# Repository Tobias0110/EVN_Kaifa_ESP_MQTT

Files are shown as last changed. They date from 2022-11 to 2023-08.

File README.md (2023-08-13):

# EVN Kaifa to MQTT
Allows you to read data from different kinds of smart power meters used by the
EVN power company in Austria. Data is read from the MBus interface (called P1),
packages are decrypted and then the values are sent to an MQTT endpoint. The
device hosts a webpage, where you can change your settings.

## 🤔 How does it work?
The ESP8266 receives the MBus data from the smart meter via a UART interface on the
front facing side of the device. A specially developed interface PCB powers the
micro-controller board from the MBus idle voltage (no extra power supply needed).
In addition, it contains a level shifter to convert from MBus voltage levels to
3V3 UART compatible with the ESP8266. This is useful because many people don't
have a power socket near their power meter.

**Please consider buying the PCB from me to support our work. You can contact me via oe3tec(at)egimoto.com**

The ESP8266 micro-controller syncs to the smartmeter's bursts of data so no packets
are lost. After receiving a package it is decrypted and the DSLM/COSEM data structure
is parsed to extract the measurement fields. These fields are then sent to an MQTT
broker in a preselected format. All relevant parameters can be configured via the
serial console at startup and are saved to the EEPROM.

Alternatively, you can update your configuration on the webpage that the ESP hosts
on the wifi network. The page is only accessible with a passcode that is set during
first setup. For more details on the webpage see below.

<p align="center">
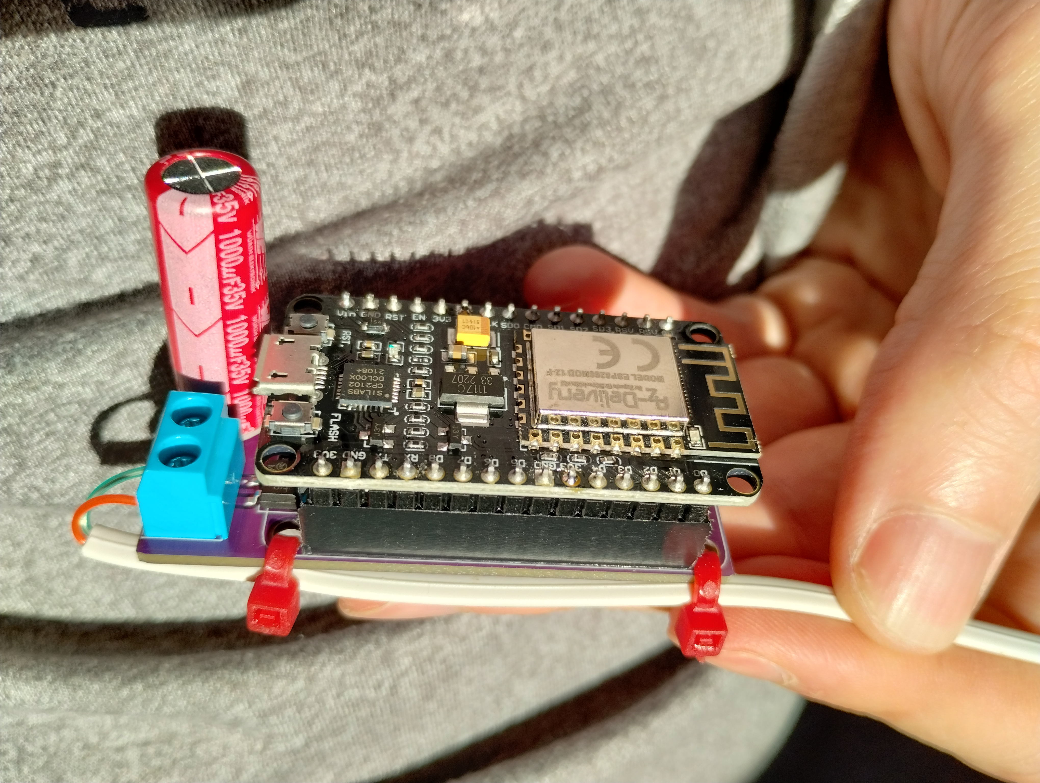
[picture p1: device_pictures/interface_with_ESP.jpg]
Complete assembly of the custom PCB and the ESP8266 on top
  
</p>

## 🔧 Installation
> **Note**
> Make sure the ESP is not connected to the interface board during programming or
> configuration.

The following steps are applicable if you are using the Arduino IDE to build the
project yourself.

1. Install [NodeJS](https://nodejs.org) on your machine, and navigate to the `www` directory.
   There, install the required npm packages by running `npm i` in your console.
2. Run the webpage build script. This should create a file named `settings-page.html.inl.h`
   next to the Arduino sketch file.
3. Install the ESP-Module as a compilation target.
    1. Add board config repository: File → Preferences →
       Paste URL into "Additional boards manager URLs": [http://arduino.esp8266.com/stable/package_esp8266com_index.json](http://arduino.esp8266.com/stable/package_esp8266com_index.json)
    2. Install the toolchain: Tools → Boards Manager → Install: esp8266
    3. Select the specific ESP module: Tools → Board → ESP2866 Boards → NodeMCU 1.0 (ESP-12E Modul)
4. Open the Library Manager pane and install the following dependecies.
    * [Crypto](https://github.com/rweather/arduino-projects) by Rhys Weatherley
    * [PubSubClient](https://github.com/knolleary/pubsubclient) by Nicholas O'Leary
    * [CRC](https://github.com/RobTillaart/CRC) by Rob Tillaart
5. Manully install the following dependencies by downloading their source code and
   dropping it into your `Arduino/Libraries` directory.
    * [ESPTrueRandom8266](https://github.com/marvinroger/ESP8266TrueRandom) by Marvin Roger
6. Click verify to check if the project builds without errors.
7. Connect the ESP module and click upload like for any other Arduino-like micro controller.
8. Connect to the ESP2866 through the serial monitor and start configuration.

## ⚙ Configuration via serial
> **Note**
> Make sure the ESP is not connected to the interface board during programming or
> configuration.

First configuration of the device is done via the serial terminal and is guided
by an interactive setup wizard. On first startup the checksum check will fail and
you will be required to enter settings. Later, you can enter the setup wizard
again during the first 10 seconds after starting by pressing 's'. You can also
clear your configuration by pressing 'c'.

1. Connect the ESP board via USB to your computer and open a serial terminal.
   Serial settings: 115200 Baud, NO Parity
2. Press reset on the ESP board.
3. On first startup the setup wizard starts immediately. Else press 's' on your
   keyboard when you are prompted to do so to edit the current settings.
4. The configuration wizard shows each settings field. Enter the data for each field
   and press return. Some fields come with default values, which are accepted by
   pressing return without any other input.
5. After start up the system switches the serial interface to MBus mode (2400 baud,
  even parity) and waits for data packets.

To boot the ESP with your settings, reset the micro-controller. All the settings fields that
can be configured are listed in the table below.

| Field name | Default value | Description |
| :--- | :--- | :--- |
WiFi SSID || SSID of the WiFi station to connect to |
WiFI password || Password of the WiFi station to connect to |
MQTT broker network address || Domain/IP of the MQTT broker server |
MQTT broker network port | 1883 | Network port of the MQTT broker server |
MQTT broker certificate fingerprint | [insecure] | SHA1 fingerprint of the SSL certificate of the MQTT broker server as hex string. If set to `[insecure]` TLS is disabled and all data is sent as plaint text |
MQTT broker user name | power-meter | User name to authenticate at the MQTT broker server |
MQTT broker password || Password to authenticate at the MQTT broker server |
MQTT broker client id || Client id to register as at the MQTT broker server |
MQTT broker path || Base path prepended to MQTT topics |
MQTT message mode | 2 | Selects the format for sending the data fields to the MQTT broker server (0 - raw, 1 - topics, 2 - json) |
Webpage key | _automatically generated random value_ | Passkey to access the webpage |
DSLM/COSEM decryption key (meter key) || Decryption key to decipher the MBus data packets provided by the power company |

> **Note**
> When reconnecting the micro-controller PCB to the interface PCB make sure that the pins align correctly.
> Also check that the USB connector points in the direction of the M-Bus connector. Wrong positioning can result in a short and damage the microcontroler.

## 🌍 Configuration via webpage
After initial setup with the serial interface and having the ESP connected to
the wifi, you can connect to the configuration webpage. To access it you need
the passkey you set before.

Due to memory limitation of the ESP8266 only a single TLS tunnel can be used at
once. As one is needed for the secure mqtt connection, there are no resources left
for the webserver. Therefore an alternative security scheme is used and the
page is hosted as plain HTTP. This means, that all your settings are always
transmitted encrypted and unreadable to others.

For security reasons, especially sensitive fields are not automatically populated
in their respective form fields. When you edited any settings and saved your changes
they will only take effect after restarting the device.

## 📬 MQTT output formats
> **Note**
> 🔐 When using secure MQTT, make sure to put `tls_version tlsv1.2` in your MQTT
> servers config file, so it only accepts encrypted connections!

The system can be configured to output the data received from the smartmeter in one
of the following formats.

### 🥩 Raw
The decryptd raw data without DSLM/COSEM parsing is sent to the broker at
`<basepath/raw>`. The data is sent as binary.

### 🐧 JSON
If the data is serialized as JSON, it is sent to the broker at `<basepath>/json`.
The json object has the following format.

| Field name  | Type | Full name  | Description |
| :--- | :--- | :--- | :--- |
| meternumber | string[12] || The unique identification number of the smartmeter |
| timestamp | ISO timestamp || Time when the measurement was taken |
| w_p | number | positive total energy | Total energy consumed |
| w_n | number | negative total energy | Total energy sent back to the grid |
| p_p | number | positive momentary power | Power currently consumed |
| p_n | number | negative momentary power | Power currently sent back to the grid |
| u1 | number | voltage on phase 1 | Momentary voltage measured on phase 1 |
| u2 | number | voltage on phase 2 | Momentary voltage measured on phase 2 |
| u3 | number | voltage on phase 3 | Momentary voltage measured on phase 3 |
| i1 | number | current on phase 1 | Momentary current measured on phase 1 |
| i2 | number | current on phase 2 | Momentary current measured on phase 2 |
| i3 | number | current on phase 3 | Momentary current measured on phase 3 |
| phi | number | power factor | Momentary power factor |
| ip | string || IP address received via DHCP |
| rssi | string | Received Signal Strength Indicator | Strength of the wifi signal in `dBm` |

The following JSON is an example package sent by the micro-controller.
```json
{
  "meternumber": "181220000009",
  "timestamp": "2021-09-27T09:47:15+02:00",
  "w_p": 12937,
  "w_n": 0,
  "p_p": 0,
  "p_n": 0,
  "u1": 233.7,
  "u2": 0,
  "u3": 0,
  "i1": 0,
  "i2": 0,
  "i3":0 ,
  "phi":1.000,
  "ip": "192.168.143.51",
  "rssi": "-52dBm"
}
```

### 🔬 Individual topics
If the data fields are sent to individual mqtt topics the following paths are used.
For a description of the fields checkout the section above.

| Field name | Full name  |
| :--- | :--- |
| `<basepath>/meternumber` ||
| `<basepath>/timestamp` ||
| `<basepath>/w_p` | positive total energy |
| `<basepath>/w_n` | negative total energy |
| `<basepath>/p_p` | positive momentary power |
| `<basepath>/p_n` | negative momentary power |
| `<basepath>/u1` | voltage on phase 1 |
| `<basepath>/u2` | voltage on phase 2 |
| `<basepath>/u3` | voltage on phase 3 |
| `<basepath>/i1` | current on phase 1 |
| `<basepath>/i2` | current on phase 2 |
| `<basepath>/i3` | current on phase 3 |
| `<basepath>/phi` | power factor |

## ☔ Standard compliance
The parsing of MBus packets, and the deserialization of the DSLM/COSEM data is
based on reverse engineering work done by [@Tobias0110](https://www.github.com/Tobias0110)
and [@PreyMa](https://www.github.com/PreyMa) as the documents defining the standard are not
publicly accessible. So there is no guarantee that anything behaves as expected,
but we try to thoroughly test the software on real hardware.

Thanks to Austrian laws power companies are required to describe how the P1 interface
on their smartmeters works at least to some degree. The following resources were
useful to understand how the communication should be implemented:

* [M-Bus Specification](https://m-bus.com/assets/downloads/MBDOC48.PDF) (version "late 90s"):
* Smart meter customer data port description (Multiple Austrian energy companies):
  * [EVN](https://www.netz-noe.at/Download-(1)/Smart-Meter/218_9_SmartMeter_Kundenschnittstelle_lektoriert_14.aspx)
  * [Stadtwerke Schwaz](https://stadtwerkeschwaz.at/pdfs/Technische%20Beschreibung%20Kundenschnittstelle%20SWS%20Smart%20Meter.pdf)
  * [Salzburg Netz](https://www.salzburgnetz.at/content/dam/salzburgnetz/dokumente/stromnetz/Technische-Beschreibung-Kundenschnittstelle.pdf)
  * [Tinetz](https://www.tinetz.at/infobereich/smart-meter/anleitungen-fragen-antworten/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)
* Python implementation of a [DLMS to XML converter](https://github.com/Gurux/Gurux.DLMS.Python/)

## ⚒ Hardware
<p align="center">
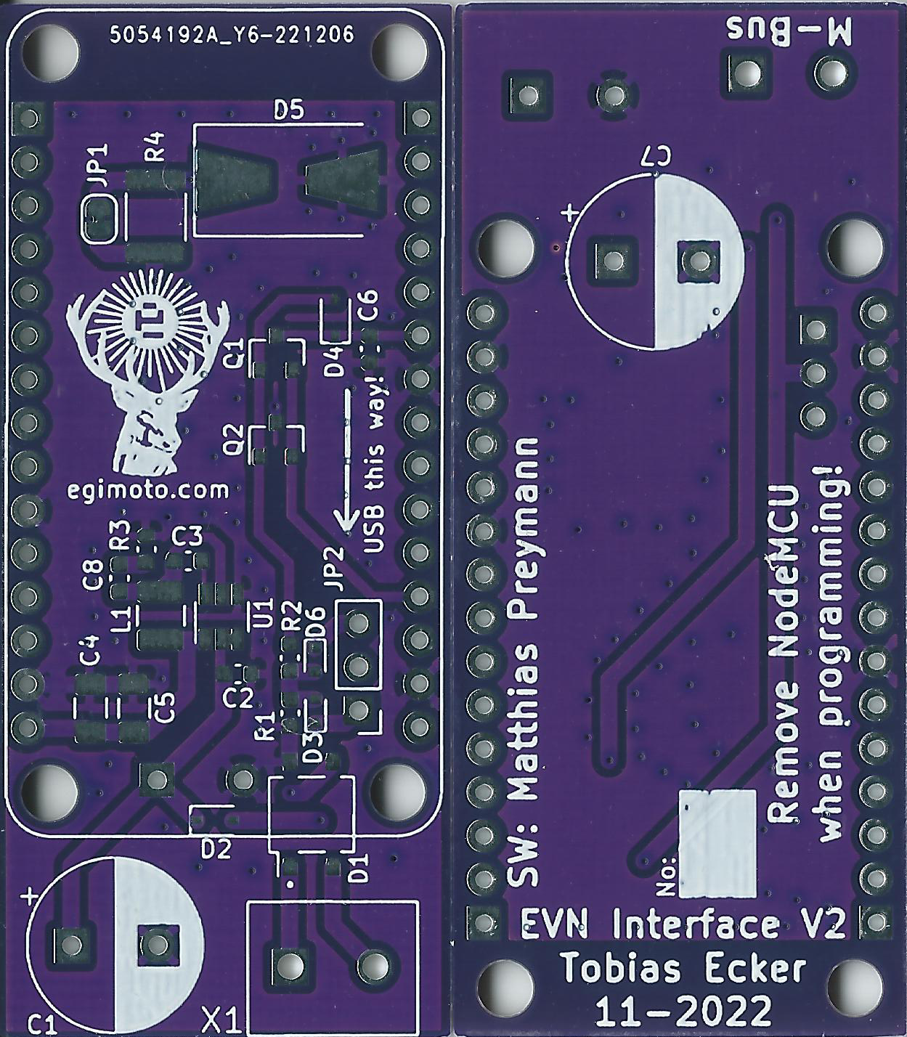
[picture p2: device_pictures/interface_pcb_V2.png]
Interface PCB version 2
  
</p>

New in Version 2:
* M-Bus over voltage protection: Protects the DC/DC converter from voltages outside its specs.
* EMC improvements of the DC/DC converter.
* Space for alternative Zener diodes to allow diffrent logic levels on the M-Bus.
* Big capacitor can be alternatively placed on the bottom side of the PCB.
* Markings for how to connect the microcontroller correctly.
* Warning to disconnect the microcontroller for programming is now on the bottom side.

## 📋 Feature roadmap
* [X] Output the clock of the smart meter in UTC
* [X] Output the smartmeter's unique id (Zählernummer)
* [X] Implement the M-Bus library and parse DSLM/COSEM data
* [X] MQTT SSL
* [X] Web server for configuration
* [ ] Expand the software to support all M-Bus smart meters in Austria
* [ ] Support for the Improv Serial standard for WiFi configuration

## 🤝 Support the project
You can support the project by purchasing the custom hardware designed by @Tobias0110.
Contact Tobias via oe3tec(at)egimoto.com

If you want to contribute to the project feel free to hack on the code and open a
pull-request. Let us know if you find any bugs or issues.

## 📜 License
This project is licensed under the GPL v2.0.

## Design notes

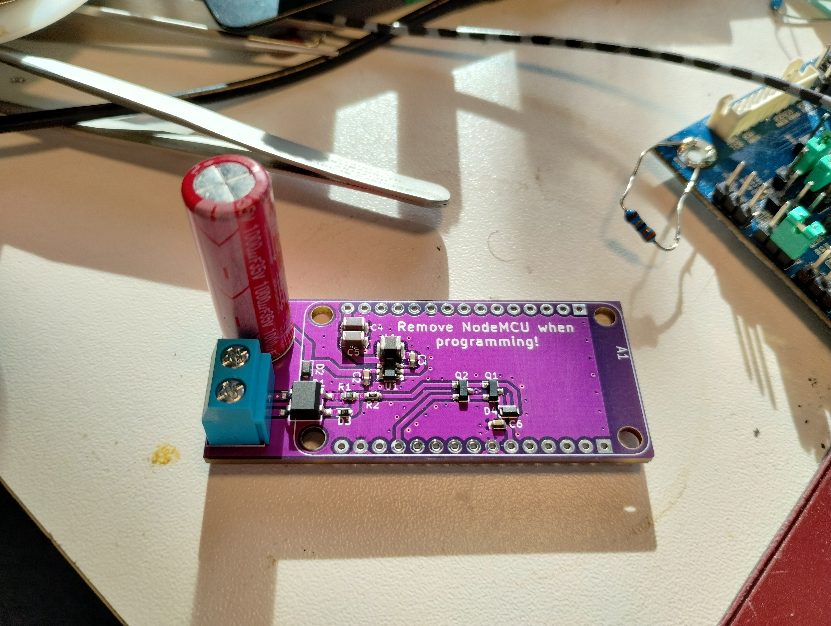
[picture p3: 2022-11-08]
device_pictures/interface_pcb.jpg

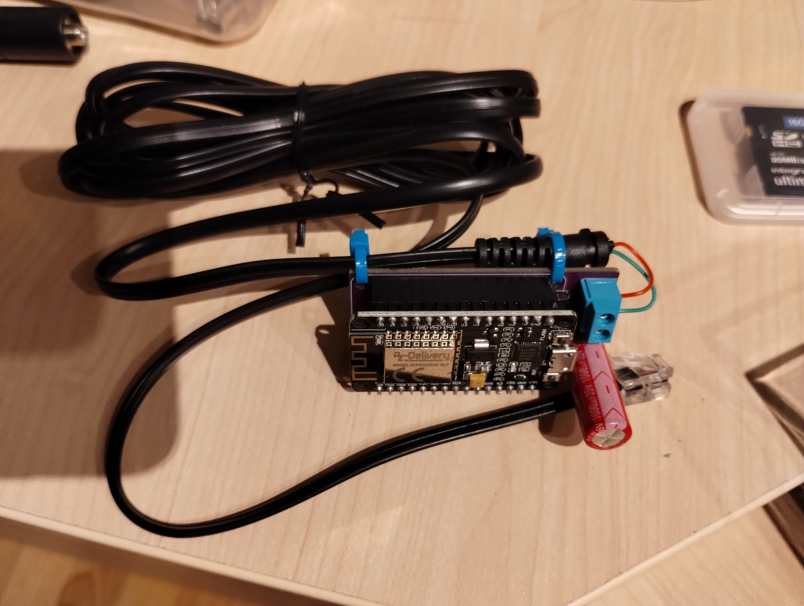
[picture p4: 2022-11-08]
device_pictures/complete_assambly.jpg

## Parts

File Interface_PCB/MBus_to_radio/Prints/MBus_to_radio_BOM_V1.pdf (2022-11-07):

MBus_to_radio

Seite 1

Source: | /mnt/a9ec076b-1377-4f94-9b3c-b0bca3a7203d/nextcloud/Projekte/Stromzaehler/EVN_meter_to_radio/Hardware/MBus_to_radio/MBus_to_radio.sch
Date: | Mo 31 Okt 2022 15:17:13
Tool: | Eeschema 5.1.5+dfsg1-2build2
Generator: | /usr/share/kicad/plugins/bom_csv_grouped_by_value_with_fp.py
Component Count: | 18
Ref | Qnty | Value | Cmp name | Footprint
A1, | | 1 NodeMCU_v2 | NodeMCU_v2 | ESP:SEEED_113990105
C1, | | 1 1000uF 50V | CP | Capacitor_THT:CP_Radial_D10.0mm_P5.00mm
C2, C3, C6, | | 3 100n | C | Capacitor_SMD:C_0603_1608Metric
C4, C5, | | 2 22u | C | Capacitor_SMD:C_1206_3216Metric
D1, | | 1 MB1S | MB2S | Package_TO_SOT_SMD:TO-269AA
D2, D4, | | 2 SS14HE | D_Schottky | Diode_SMD:D_SOD-323
D3, | 1 SZMM5Z16VT5GF D_Zener | Diode_SMD:D_SOD-523
L1, | 1 CBC3225T4R7MRV L | Inductor_SMD:L_1210_3225Metric
Q1, | | 1 BC847 | BC847 | Package_TO_SOT_SMD:SOT-23
Q2, | | 1 BC857 | BC857 | Package_TO_SOT_SMD:SOT-23
R1, | | 1 10k | R | Resistor_SMD:R_0603_1608Metric
R2, | | 1 1.8k | R | Resistor_SMD:R_0603_1608Metric
U1, | | 1 AP63205WU-7 | AP63205WU-7 | Package_TO_SOT_SMD:TSOT-23-6
X1, | 1 TB003-500-P02BE TB003-500-P02BE ESP:CUI_TB003-500-P02BE

MBus_to_radio

Seite 2

Description | Vendor

Polarized capacitor
Unpolarized capacitor
Unpolarized capacitor
Miniature Glass Passivated Single-Phase Surface Mount Bridge Rectifiers, 140V Vrms, 0.5A If, TO-269AA Schottky diode
Zener diode
Inductor
0.1A Ic, 45V Vce, NPN Transistor, SOT-23 0.1A Ic, 45V Vce, PNP Transistor, SOT-23 Resistor
Resistor

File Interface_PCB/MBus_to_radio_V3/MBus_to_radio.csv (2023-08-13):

Source: | /mnt/a9ec076b-1377-4f94-9b3c-b0bca3a7203d/nextcloud/Projekte/Stromzaehler/EVN_Kaifa_ESP_MQTT/Interface_PCB/MBus_to_radio_V3/MBus_to_radio.sch
Date: | Di 09 Mai 2023 09:25:55
Tool: | Eeschema 5.1.5+dfsg1-2build2
Generator: | /usr/share/kicad/plugins/bom_csv_grouped_by_value_with_fp.py
Component Count: | 66
Ref | Qnty | Value | Cmp name | Footprint | Description | Vendor
C1, | 1 | 100uF 80V | CP | Capacitor_SMD:CP_Elec_10x10 | Polarized capacitor
C2, | 1 | 220n 100V | C | Capacitor_SMD:C_1206_3216Metric | Unpolarized capacitor
C3, | 1 | 100n 100V | C | Capacitor_SMD:C_0603_1608Metric | Unpolarized capacitor
C4, | 1 | 47u 5V | C | Capacitor_SMD:C_1206_3216Metric | Unpolarized capacitor
C5, | 1 | 1u 10V | C | Capacitor_SMD:C_0603_1608Metric | Unpolarized capacitor
C6, C7, C10, C12, | 4 | 100n 50V | C | Capacitor_SMD:C_0603_1608Metric | Unpolarized capacitor
C8, | 1 | ? | C | Capacitor_SMD:C_0603_1608Metric | Unpolarized capacitor
C9, C11, | 2 | 33p | C | Capacitor_SMD:C_0402_1005Metric | Unpolarized capacitor
D1, D2, D3, D4, D6, D7, D8, D9, | 8 | DSK110 | D_Schottky | Diode_SMD:D_SOD-123 | Schottky diode
D5, | 1 | Purple | LED | LED_SMD:LED_0402_1005Metric | Light emitting diode
D10, | 1 | Green | LED | LED_SMD:LED_0402_1005Metric | Light emitting diode
D11, D12, | 2 | AU0561M1S | D_TVS | Diode_SMD:D_0402_1005Metric | Bidirectional transient-voltage-suppression diode
D13, D14, D15, D16, | 4 | SMF40CA | D_TVS | Diode_SMD:D_SOD-123F | Bidirectional transient-voltage-suppression diode
H1, H2, H3, H4, | 4 | M2.5 | MountingHole_Pad | MountingHole:MountingHole_2.5mm_Pad_Via | Mounting Hole with connection
J1, | 1 | USB_C_USB-TYPE-C-019 | USB_C_USB-TYPE-C-019 | Connector_USB:USB-TYPE-C-019 | USB Full-Featured Type-C Receptacle connector
JP1, | 1 | Reset | SolderJumper_2_Open | Jumper:SolderJumper-2_P1.3mm_Open_RoundedPad1.0x1.5mm | Solder Jumper, 2-pole, open
JP2, | 1 | Flash | SolderJumper_2_Open | Jumper:SolderJumper-2_P1.3mm_Open_RoundedPad1.0x1.5mm | Solder Jumper, 2-pole, open
JP3, | 1 | Debug M-Bus via UART to USB | SolderJumper_3_Bridged12 | Jumper:SolderJumper-3_P1.3mm_Bridged12_RoundedPad1.0x1.5mm_NumberLabels | 3-pole Solder Jumper, pins 1+2 closed/bridged
L1, | 1 | CMLO1040H220MTT | CMLO1040H220MTT | Inductor_SMD:L_10.4x10.4_H4.8 | 4A 22uH ±20% SMD Power Inductors ROHS
Q1, | 1 | MMDT3904DW | MMDT3904DW | Package_TO_SOT_SMD:SOT-363_SC-70-6 | Dual NPN transistor, 6 pin package
R1, | 1 | 10k | R | Resistor_SMD:R_0603_1608Metric | Resistor
R2, | 1 | 130k | R | Resistor_SMD:R_0603_1608Metric | Resistor
R3, | 1 | ? | R | Resistor_SMD:R_0603_1608Metric | Resistor
R4, | 1 | 100k | R | Resistor_SMD:R_0603_1608Metric | Resistor
R5, R6, R7, R9, R10, R13, R14, R15, R18, R19, | 10 | 10k | R | Resistor_SMD:R_0402_1005Metric | Resistor
R8, | 1 | 1.8k | R | Resistor_SMD:R_0402_1005Metric | Resistor
R11, R12, | 2 | 5.1k | R | Resistor_SMD:R_0402_1005Metric | Resistor
R16, | 1 | 100k | R | Resistor_SMD:R_0402_1005Metric | Resistor
R17, | 1 | 43k | R | Resistor_SMD:R_0402_1005Metric | Resistor
R20, R21, | 2 | 470R | R | Resistor_SMD:R_0402_1005Metric | Resistor
U1, | 1 | LMR36510FA | LMR36510FA | Package_SO:SOIC-8-1EP_3.9x4.9mm_P1.27mm_EP2.29x3mm_ThermalVias | DC/DC Converter
U2, | 1 | LM393 | LM393 | Package_SO:SOIC-8_3.9x4.9mm_P1.27mm | Low-Power, Low-Offset Voltage, Dual Comparators, DIP-8/SOIC-8/SSOP-8
U3, | 1 | ESP-12F | ESP-12F | RF_Module:ESP-12E | 802.11 b/g/n Wi-Fi Module
U4, | 1 | CH340C | CH340C | Package_SO:SOIC-16_3.9x9.9mm_P1.27mm | USB serial converter, UART, SOIC-16
X1, | 1 | WJ350V-3.96-2P-14-00A | WJ350V-3.96-2P-14-00A | ESP:WJ350V-3.96-2P-14-00A | P=3.96mm Screw terminal ROHS
Y1, | 1 | 12MHz THT | Crystal | Crystal:Crystal_HC49-U_Vertical | Two pin crystal
Y2, | 1 | HY12MSMD3225OB1R30 | Crystal_GND24 | Crystal:Crystal_SMD_EuroQuartz_MT-4Pin_3.2x2.5mm | Four pin crystal, GND on pins 2 and 4

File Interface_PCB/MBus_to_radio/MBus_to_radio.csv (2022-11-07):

Source: | /mnt/a9ec076b-1377-4f94-9b3c-b0bca3a7203d/nextcloud/Projekte/Stromzaehler/EVN_meter_to_radio/Hardware/MBus_to_radio/MBus_to_radio.sch
Date: | Mo 31 Okt 2022 15:17:13
Tool: | Eeschema 5.1.5+dfsg1-2build2
Generator: | /usr/share/kicad/plugins/bom_csv_grouped_by_value_with_fp.py
Component Count: | 18
Ref | Qnty | Value | Cmp name | Footprint | Description | Vendor
A1, | 1 | NodeMCU_v2 | NodeMCU_v2 | ESP:SEEED_113990105
C1, | 1 | 1000uF 50V | CP | Capacitor_THT:CP_Radial_D10.0mm_P5.00mm | Polarized capacitor
C2, C3, C6, | 3 | 100n | C | Capacitor_SMD:C_0603_1608Metric | Unpolarized capacitor
C4, C5, | 2 | 22u | C | Capacitor_SMD:C_1206_3216Metric | Unpolarized capacitor
D1, | 1 | MB1S | MB2S | Package_TO_SOT_SMD:TO-269AA | Miniature Glass Passivated Single-Phase Surface Mount Bridge Rectifiers, 140V Vrms, 0.5A If, TO-269AA
D2, D4, | 2 | SS14HE | D_Schottky | Diode_SMD:D_SOD-323 | Schottky diode
D3, | 1 | SZMM5Z16VT5GF | D_Zener | Diode_SMD:D_SOD-523 | Zener diode
L1, | 1 | CBC3225T4R7MRV | L | Inductor_SMD:L_1210_3225Metric | Inductor
Q1, | 1 | BC847 | BC847 | Package_TO_SOT_SMD:SOT-23 | 0.1A Ic, 45V Vce, NPN Transistor, SOT-23
Q2, | 1 | BC857 | BC857 | Package_TO_SOT_SMD:SOT-23 | 0.1A Ic, 45V Vce, PNP Transistor, SOT-23
R1, | 1 | 10k | R | Resistor_SMD:R_0603_1608Metric | Resistor
R2, | 1 | 1.8k | R | Resistor_SMD:R_0603_1608Metric | Resistor
U1, | 1 | AP63205WU-7 | AP63205WU-7 | Package_TO_SOT_SMD:TSOT-23-6
X1, | 1 | TB003-500-P02BE | TB003-500-P02BE | ESP:CUI_TB003-500-P02BE

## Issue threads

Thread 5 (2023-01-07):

Watchdog timer triggers software reset when not synced with meter

Tobias0110, 2023-01-07:
When sending meter data to the µC just before a serial timeout, the watchdog timer is triggered with the following stack trace:

    --------------- CUT HERE FOR EXCEPTION DECODER ---------------

    Soft WDT reset

    >>>stack>>>

    ctx: cont
    sp: 3ffff560 end: 402201c7 offset: 01a0
    3ffff700:  0a048a22 3ffff730 3fff7f6c 40208706
    3ffff710:  00000000 3fff6e34 3fff0634 00003a98
    3ffff720:  00000000 0005346d 3fff0634 40205428
    3ffff730:  000000d8 d86f2dc3 5583ff70 3ea34baf
    3ffff740:  00000008 00000001 000285ea 00000000
    3ffff750:  40222b94 40222be4 3fff7f6c 402221d2
    3ffff760:  3fff846c 3ffef0e0 3fff7f6c 3ffef0e0
    3ffff770:  00000000 00000001 3fff0634 40205547
    3ffff780:  00000000 00000001 3fff0634 40205737
    3ffff790:  00000003 3ffef414 00000001 40208634
    3ffff7a0:  00000000 00000000 00006fcf 40208d3a
    3ffff7b0:  00000000 3fff0a44 3fff0634 40204582
    3ffff7c0:  3fff7e2c 00000020 3fff7dfc 3ffef118
    3ffff7d0:  00006fcf 3ffef0e0 3fff0634 3ffef118
    3ffff7e0:  00006fcf 3ffef0e0 3fff0634 402057d9
    3ffff7f0:  4020c150 e31a2e3e 4020c150 e31a2e3e
    3ffff800:  00000000 3fff2881 3fff2896 4020ae0e
    3ffff810:  0000012c 3fff2881 3fff2896 40206150
    3ffff820:  3fff7b9c 3fff7dfc 00000000 40214ba3
    3ffff830:  00000000 3fff286c 0000

'

    --------------- CUT HERE FOR EXCEPTION DECODER ---------------

    Soft WDT reset

    >>>stack>>>

    ctx: sys
    sp: 3ffff580 end: 3fffffb0 offset: 01a0
    3ffff720:  00000000 0005cd33 3fff0634 4020543c
    3ffff730:  000000d8 edbc03cd 762b36a4 699b00cf
    3ffff740:  00000008 00000001 00005872 00000000
    3ffff750:  40222b94 40222be4 3fff2afc 402221d2
    3ffff760:  3fff2ffc 3ffef0e0 3fff2afc 3ffef0e0
    3ffff770:  00000000 00000001 3fff0634 40205547
    3ffff780:  00000000 00000001 3fff0634 40205737
    3ffff790:  00000002 3ffef414 00000001 40208634
    3ffff7a0:  00000000 00000000 00006fcf 40208d3a
    3ffff7b0:  00000000 3fff0a44 3fff0634 40204582
    3ffff7c0:  3fff00bc 00003930 0000000b 3ffef118
    3ffff7d0:  00006fcf 3ffef0e0 3fff0634 3ffef118
    3ffff7e0:  00006fcf 3ffef0e0 3fff0634 402057d9
    3ffff7f0:  4020c150 e31a2e3e 4020c150 e31a2e3e
    3ffff800:  00000000 3fff2881 3fff2896 4020ae0e
    3ffff810:  000023ff 3fff2881 3fff2896 40206150
    3ffff820:  00000008 00000000 000021fe 00000009
    3ffff830:  00000000 3fff286c 00000000 00000000
    3ffff840:  00000001 0000000b 000003e8 0000fffd
    3ffff850:  00000000 3fff0634 3ff
'

    --------------- CUT HERE FOR EXCEPTION DECODER ---------------

    Soft WDT reset

    >>>stack>>>

    ctx: sys
    sp: 3ffff570 end: 3fffffb0 offset: 01a0
    3ffff710:  00000000 3fff6c3c 3fff0634 40203e62
    3ffff720:  00000000 0005b922 3fff0634 4020541f
    3ffff730:  000000d8 1805f4b9 d3e7cf56 7010db7f
    3ffff740:  00000008 00000001 00021a9b 00000000
    3ffff750:  40222b94 40222be4 3fff7e3c 402221d2
    3ffff760:  3fff833c 3ffef0e0 3fff7e3c 3ffef0e0
    3ffff770:  00000000 00000001 3fff0634 40205547
    3ffff780:  00000000 00000001 3fff0634 40205737
    3ffff790:  00000002 3ffef414 00000001 40208634
    3ffff7a0:  00000000 00000000 00006fcf 40208d3a
    3ffff7b0:  00000000 3fff0a44 3fff0634 40204582
    3ffff7c0:  3fff6ecc 00000020 3fff6e9c 3ffef118
    3ffff7d0:  00006fcf 3ffef0e0 3fff0634 3ffef118
    3ffff7e0:  00006fcf 3ffef0e0 3fff0634 402057d9
    3ffff7f0:  4020c150 e31a2e3e 4020c150 e31a2e3e
    3ffff800:  00000000 3fff2881 3fff2896 4020ae0e
    3ffff810:  0000012c 3fff2881 3fff2896 40206150
    3ffff820:  3fff6c3c 3fff6e9c 00000000 40214ba3
    3ffff830:  00000000 3fff286c 00000000 00000000
    3ffff840:  00000001 00000000 000

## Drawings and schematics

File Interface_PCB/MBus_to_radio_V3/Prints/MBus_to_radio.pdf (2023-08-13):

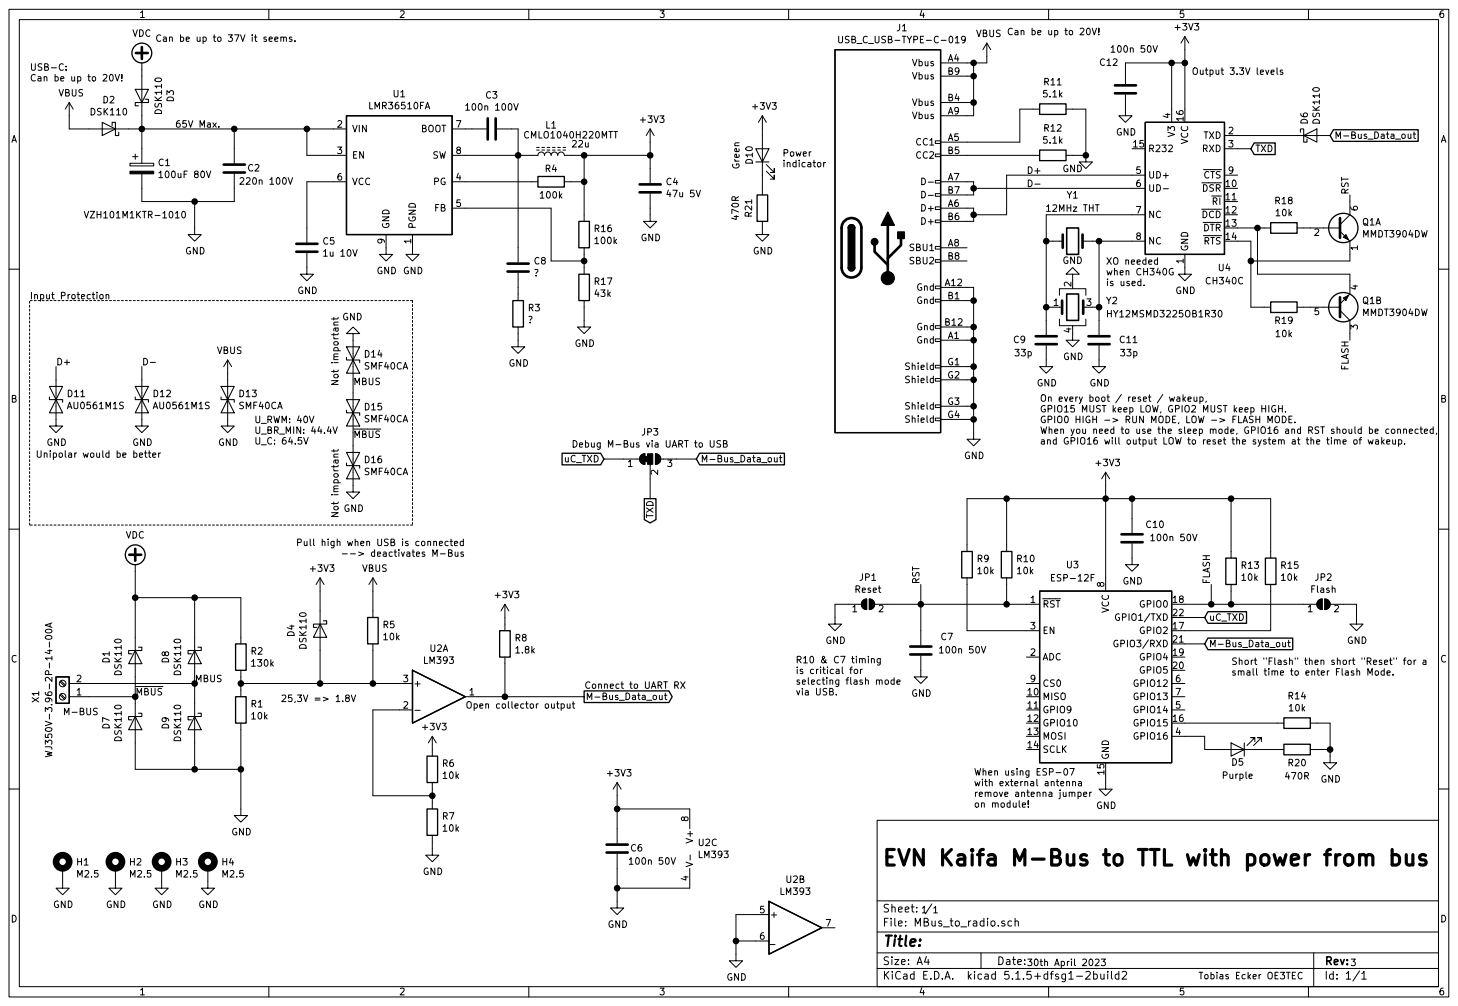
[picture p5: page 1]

1 VIN 2 EN 3 PG 4 FB 5 VCC 6 BOOT 7 SW 8 GND

1 DSR 10 RI 11 DCD 12 DTR 13 RTS 14 R232 15 VCC 16 TXD 2 RXD 3 V3

4 UD+ 5 UD- 6 NC 7 NC 8 CTS 9 U4 CH340C

EVN Kaifa M-Bus to TTL with power from bus Not important

JP3 Debug M-Bus via UART to USB D15 SMF40CA GND

GPIO15 MUST keep LOW, GPIO2 MUST keep HIGH. GPIO0 HIGH -> RUN MODE, LOW -> FLASH MODE. When you need to use the sleep mode, GPIO16 and RST should be connected,

and GPIO16 will output LOW to reset the system at the time of wakeup. 25,3V => 1.8V M-BUS

Pull high when USB is connected

small time to enter Flash Mode. Open collector output

R10 & C7 timing
is critical for selecting flash mode

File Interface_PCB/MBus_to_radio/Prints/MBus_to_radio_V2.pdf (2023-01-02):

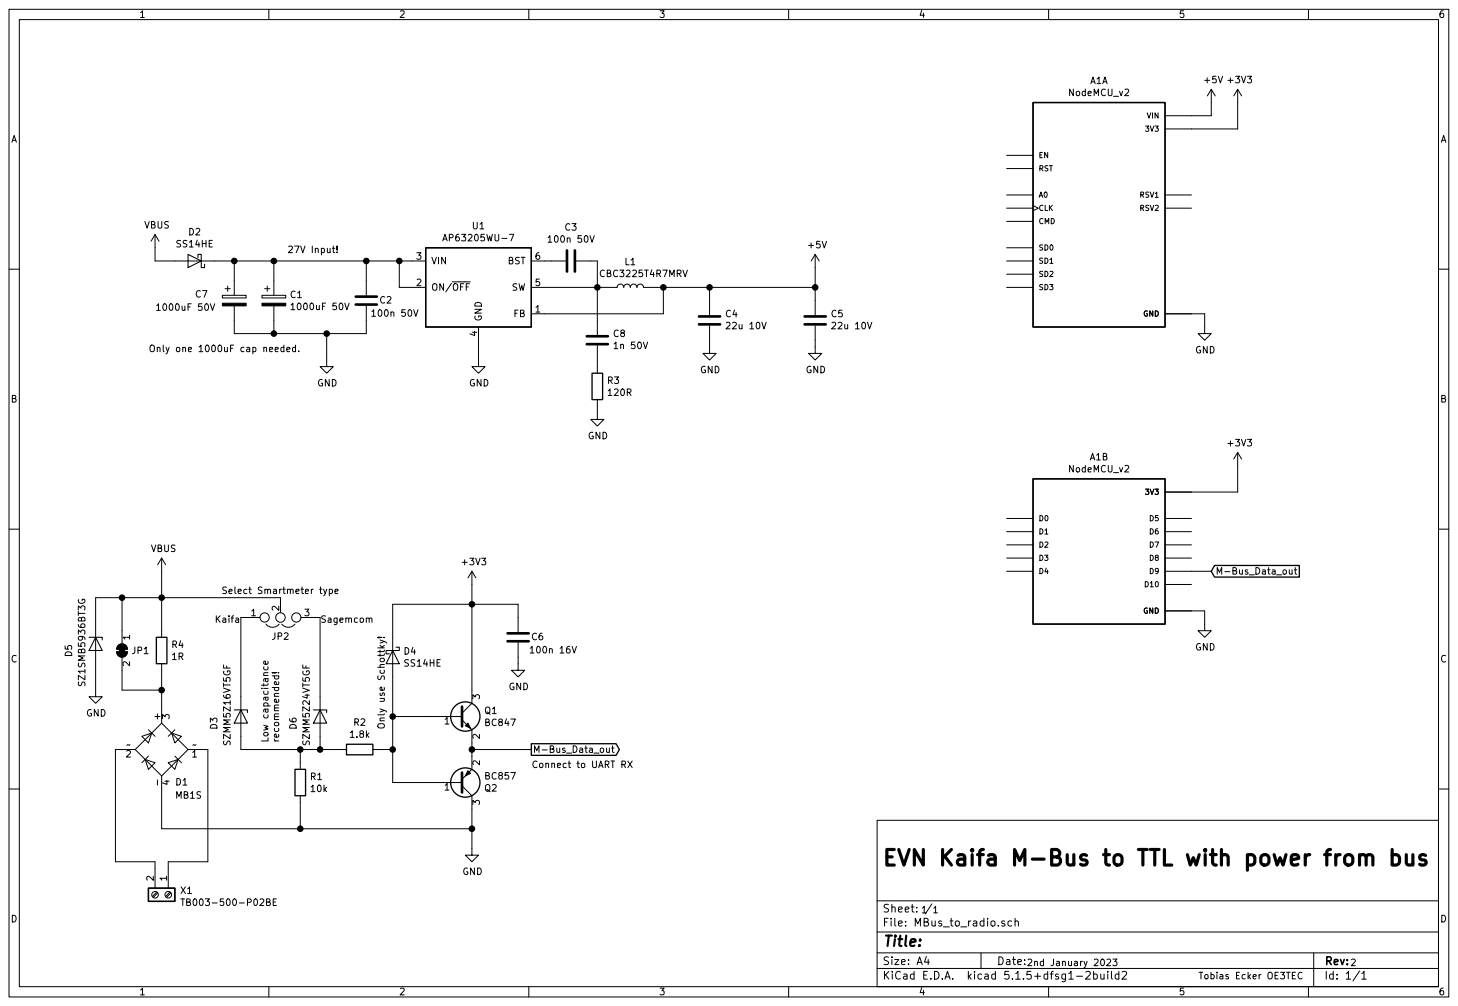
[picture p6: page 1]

Only one 1000uF cap needed.

EVN Kaifa M-Bus to TTL with power from bus

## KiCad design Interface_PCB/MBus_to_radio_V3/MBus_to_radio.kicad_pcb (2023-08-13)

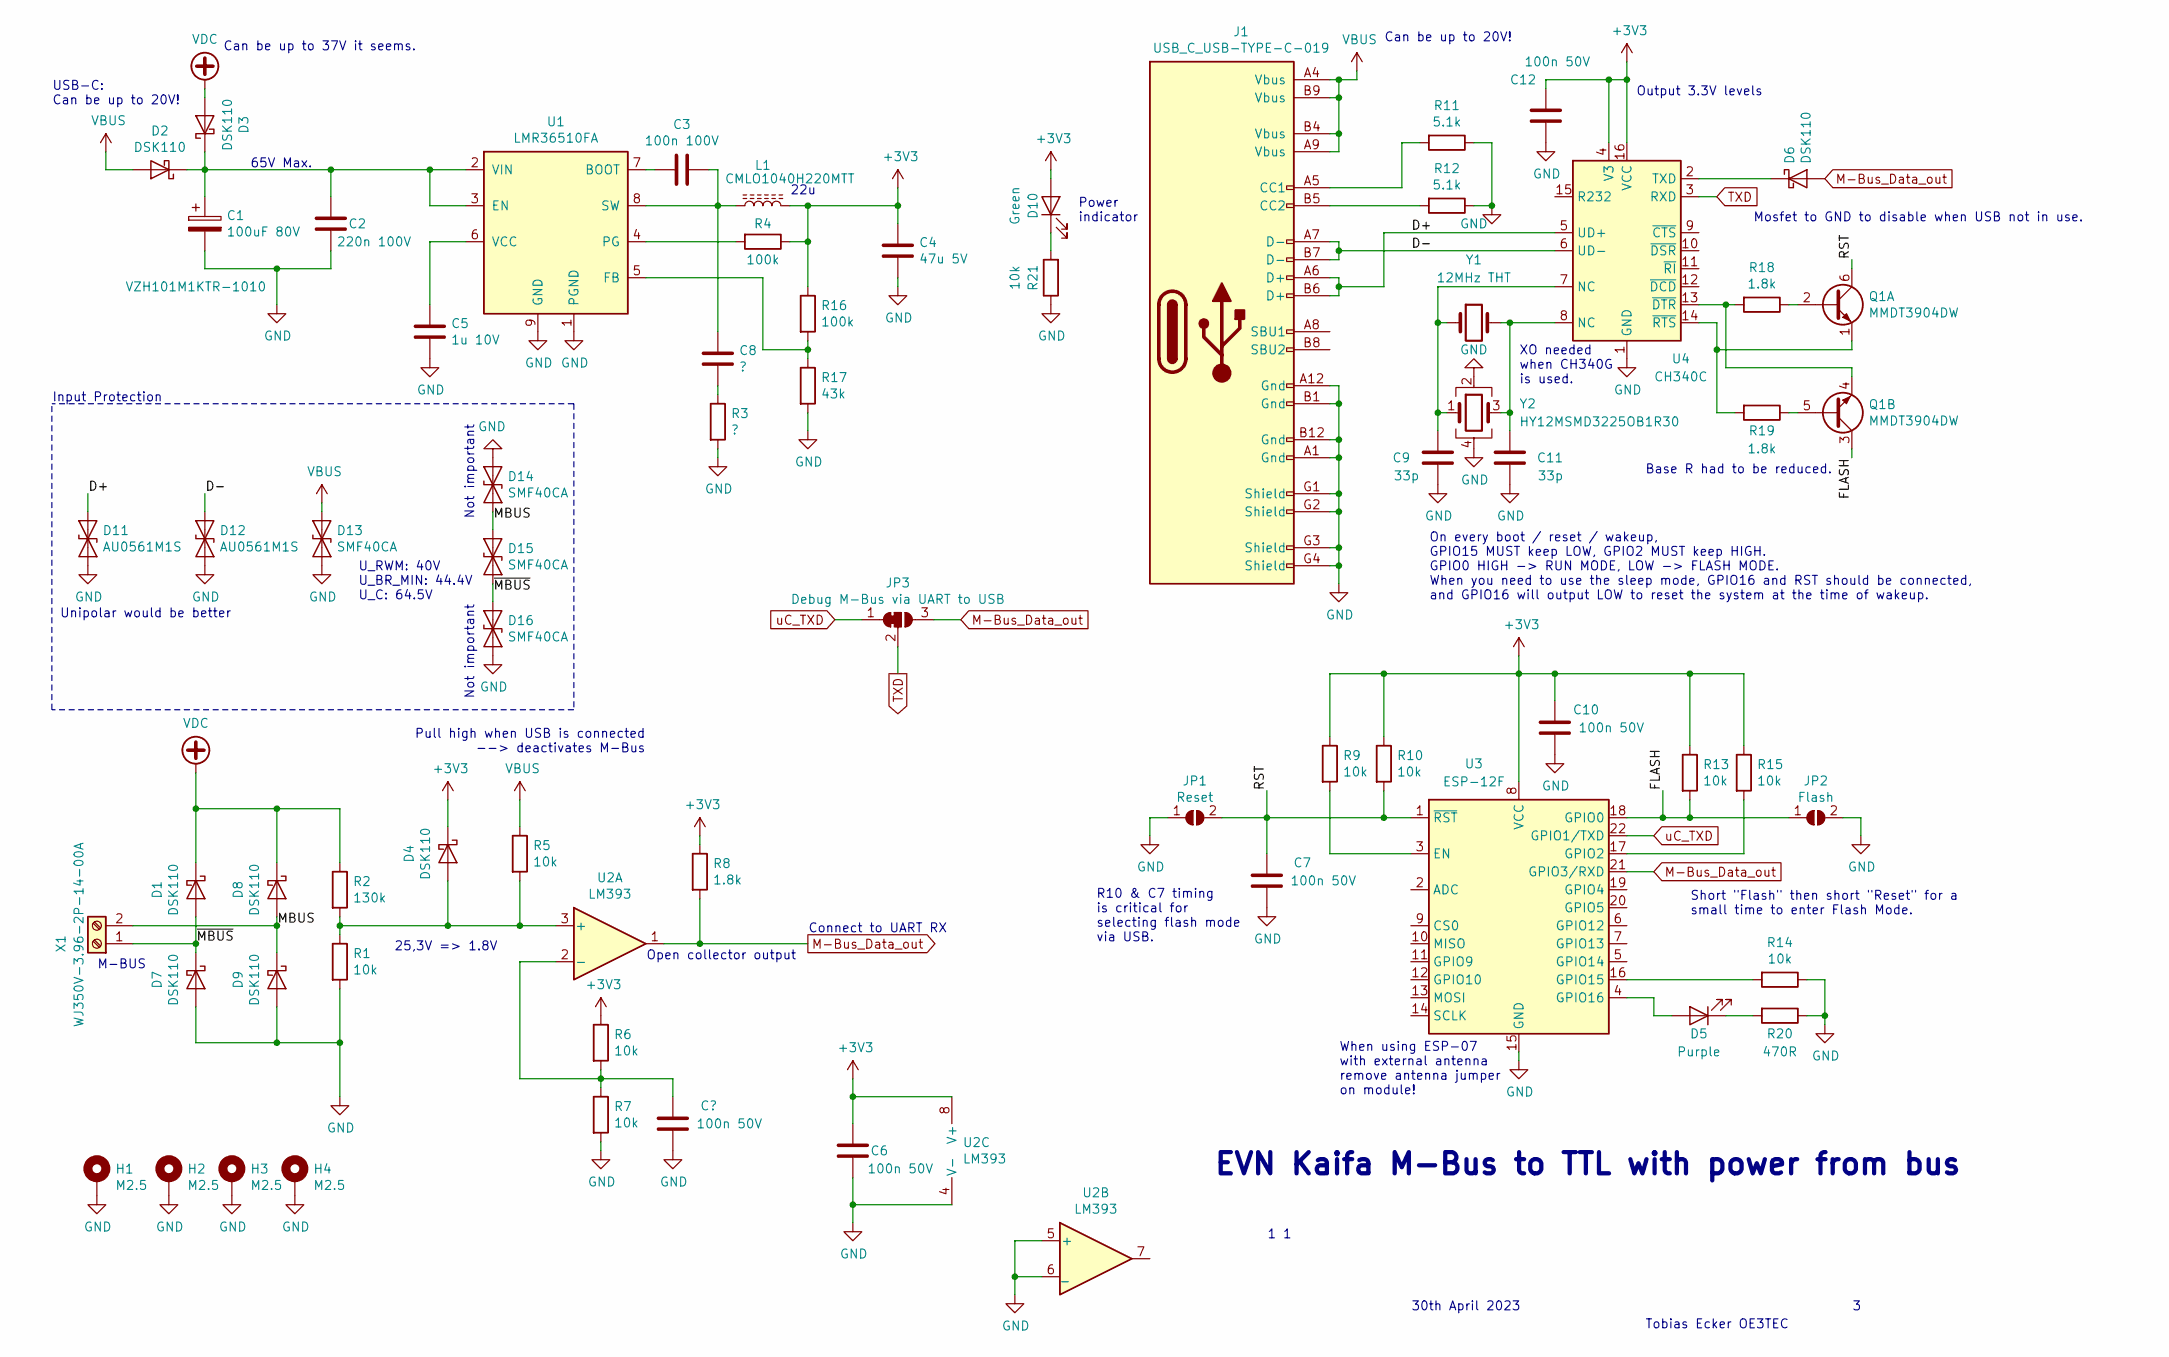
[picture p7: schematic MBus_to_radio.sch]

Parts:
C1: 100uF 80V; CP_Elec_10x10
C2: 220n 100V; C_1206_3216Metric
C3: 100n 100V; C_0603_1608Metric
C4: 47u 5V; C_1206_3216Metric
C5: 1u 10V; C_0603_1608Metric
C6, C7, C10, C12: 100n 50V; C_0603_1608Metric
C8: ?; C_0603_1608Metric
C9, C11: 33p; C_0402_1005Metric
D1, D2, D3, D4, D6, D7, D8, D9: DSK110; D_SOD-123
D5: Purple; LED_0402_1005Metric
D10: Green; LED_0402_1005Metric
D11, D12: AU0561M1S; D_0402_1005Metric
D13, D14, D15, D16: SMF40CA; D_SOD-123F
H1, H2, H3, H4: M2.5; MountingHole_2.5mm_Pad_Via
J1: USB_C_USB-TYPE-C-019; USB-TYPE-C-019
JP1: Reset; SolderJumper-2_P1.3mm_Open_RoundedPad1.0x1.5mm
JP2: Flash; SolderJumper-2_P1.3mm_Open_RoundedPad1.0x1.5mm
JP3: Debug M-Bus via UART to USB; SolderJumper-3_P1.3mm_Bridged12_RoundedPad1.0x1.5mm_NumberL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
L1: CMLO1040H220MTT; L_10.4x10.4_H4.8
Q1: MMDT3904DW; SOT-363_SC-70-6
R1: 10k; R_0603_1608Metric
R2: 130k; R_0603_1608Metric
R3: ?; R_0603_1608Metric
R4: 100k; R_0603_1608Metric
R5, R6, R7, R9, R10, R13, R14, R15, R21: 10k; R_0402_1005Metric
R8, R18, R19: 1.8k; R_0402_1005Metric
R11, R12: 5.1k; R_0402_1005Metric
R16: 100k; R_0402_1005Metric
R17: 43k; R_0402_1005Metric
R20: 470R; R_0402_1005Metric
U1: LMR36510FA; SOIC-8-1EP_3.9x4.9mm_P1.27mm_EP2.29x3mm_ThermalVias
U2: LM393; SOIC-8_3.9x4.9mm_P1.27mm
U3: ESP-12F; ESP-12E
U4: CH340C; SOIC-16_3.9x9.9mm_P1.27mm
X1: WJ350V-3.96-2P-14-00A
Y1: 12MHz THT; Crystal_HC49-U_Vertical
Y2: HY12MSMD3225OB1R30; Crystal_SMD_EuroQuartz_MT-4Pin_3.2x2.5mm

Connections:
+3V3: C4.2, C6.2, C10.2, C12.2, D4.1 (K), D10.2 (A), L1.2, R4.1, R6.1, R8.1, R9.1, R10.1, R13.1, R15.1, R16.1, U2.8 (V+), U3.8 (VCC), U4.4 (V3), U4.16 (VCC)
/D+: D11.1 (A1), J1.A6 (D+), J1.B6 (D+), U4.5 (UD+)
/D-: D12.1 (A1), J1.A7 (D-), J1.B7 (D-), U4.6 (UD-)
/FLASH: JP2.1 (A), Q1.3 (C2), R13.2, U3.18 (GPIO0)
/MBUS: D8.2 (A), D9.1 (K), D14.2 (A2), D15.1 (A1), X1.2
/RST: C7.2, JP1.2 (B), Q1.6 (C1), R10.2, U3.1 (~RST)
/~MBUS: D1.2 (A), D7.1 (K), D15.2 (A2), D16.1 (A1), X1.1
GND: C1.2, C2.1, C4.1, C5.1, C6.1, C7.1, C9.1, C10.1, C11.1, C12.1, D7.2 (A), D9.2 (A), D11.2 (A2), D12.2 (A2), D13.2 (A2), D14.1 (A1), D16.2 (A2), H1.1, H2.1, H3.1, H4.1, J1.A1 (Gnd), J1.A12 (Gnd), J1.B1 (Gnd), J1.B12 (Gnd), J1.G1 (Shield), J1.G2 (Shield), J1.G3 (Shield), J1.G4 (Shield), JP1.1 (A), JP2.2 (B), R1.2, R3.2, R7.2, R11.1, R12.1, R14.1, R17.2, R20.1, R21.1, U1.1 (PGND), U1.9 (GND), U2.4 (V-), U2.5 (+), U2.6 (_), U3.15 (GND), U4.1 (GND), Y2.2, Y2.4
M-Bus_Data_out: D6.2 (A), JP3.3 (B), R8.2, U2.1, U3.21 (GPIO3/RXD)
unnamed: C1.1, C2.2, D2.1 (K), D3.1 (K), U1.2 (VIN), U1.3 (EN)
unnamed: C3.1, U1.7 (BOOT)
unnamed: C3.2, C8.2, L1.1, U1.8 (SW)
unnamed: C5.2, U1.6 (VCC)
unnamed: C8.1, R3.1
unnamed: C9.2, U4.7 (NC), Y1.1, Y2.1
unnamed: C11.2, U4.8 (NC), Y1.2, Y2.3
unnamed: D4.2 (A), R1.1, R2.2, R5.2, U2.3 (+)
unnamed: D5.1 (K), R20.2
unnamed: D5.2 (A), U3.4 (GPIO16)
unnamed: D6.1 (K), U4.2 (TXD)
unnamed: D10.1 (K), R21.2
unnamed: J1.A5 (CC1), R11.2
unnamed: J1.B5 (CC2), R12.2
unnamed: Q1.1 (E1), R19.2, U4.14 (~RTS)
unnamed: Q1.2 (B1), R18.1
unnamed: Q1.4 (E2), R18.2, U4.13 (~DTR)
unnamed: Q1.5 (B2), R19.1
unnamed: R4.2, U1.4 (PG)
unnamed: R6.2, R7.1, U2.2 (-)
unnamed: R9.2, U3.3 (EN)
unnamed: R14.2, U3.16 (GPIO15)
unnamed: R15.2, U3.17 (GPIO2)
unnamed: R16.2, R17.1, U1.5 (FB)
TXD: JP3.2 (C), U4.3 (RXD)
VBUS: D2.2 (A), D13.1 (A1), J1.A4 (Vbus), J1.A9 (Vbus), J1.B4 (Vbus), J1.B9 (Vbus), R5.1
VDC: D1.1 (K), D3.2 (A), D8.1 (K), R2.1
uC_TXD: JP3.1 (A), U3.22 (GPIO1/TXD)

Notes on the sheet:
EVN Kaifa M-Bus to TTL with power from bus
1 1
30th April 2023
Tobias Ecker OE3TEC
Connect to UART RX
Pull high when USB is connected --> deactivates M-Bus
Open collector output
Short "Flash" then short "Reset" for a small time to enter Flash Mode.
25,3V => 1.8V
On every boot / reset / wakeup, GPIO15 MUST keep LOW, GPIO2 MUST keep HIGH. GPIO0 HIGH -> RUN MODE, LOW -> FLASH MODE. When you need to use the sleep mode, GPIO16 and RST should be connected, and GPIO16 will output LOW to reset the system at the time of wakeup.
65V Max.
XO needed when CH340G is used.
Output 3.3V levels
R10 & C7 timing is critical for selecting flash mode via USB.
When using ESP-07 with external antenna remove antenna jumper on module!
M-BUS
Power indicator
22u
Can be up to 20V!
USB-C: Can be up to 20V!
Can be up to 37V it seems.
Input Protection
U_RWM: 40V U_BR_MIN: 44.4V U_C: 64.5V
Not important
Unipolar would be better
Base R had to be reduced.
Mosfet to GND to disable when USB not in use.

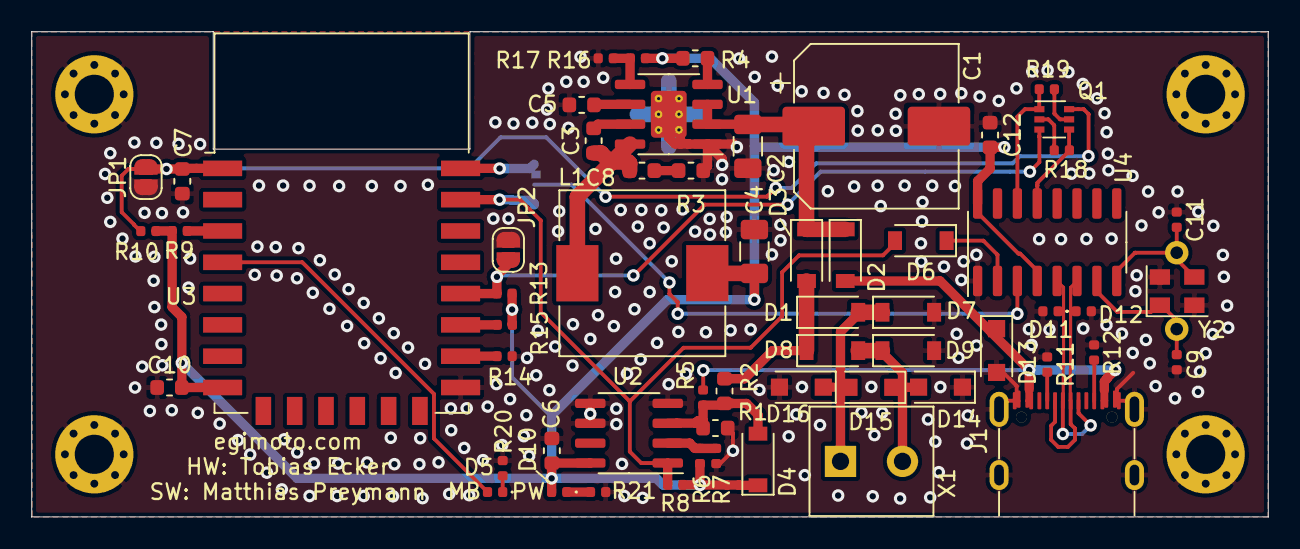
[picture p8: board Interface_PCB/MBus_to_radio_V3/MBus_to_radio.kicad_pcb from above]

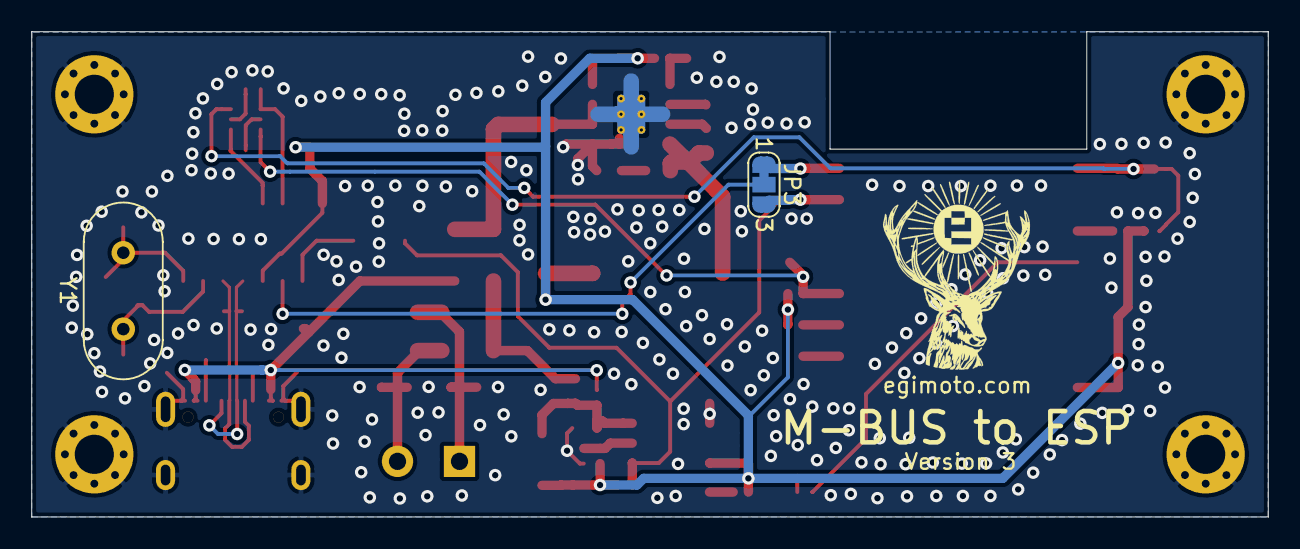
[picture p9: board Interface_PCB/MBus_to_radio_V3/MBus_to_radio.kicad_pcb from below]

Board: 2 copper layers, 79.0 x 31.0 mm, 66 parts (2 on the bottom side), 37 nets.

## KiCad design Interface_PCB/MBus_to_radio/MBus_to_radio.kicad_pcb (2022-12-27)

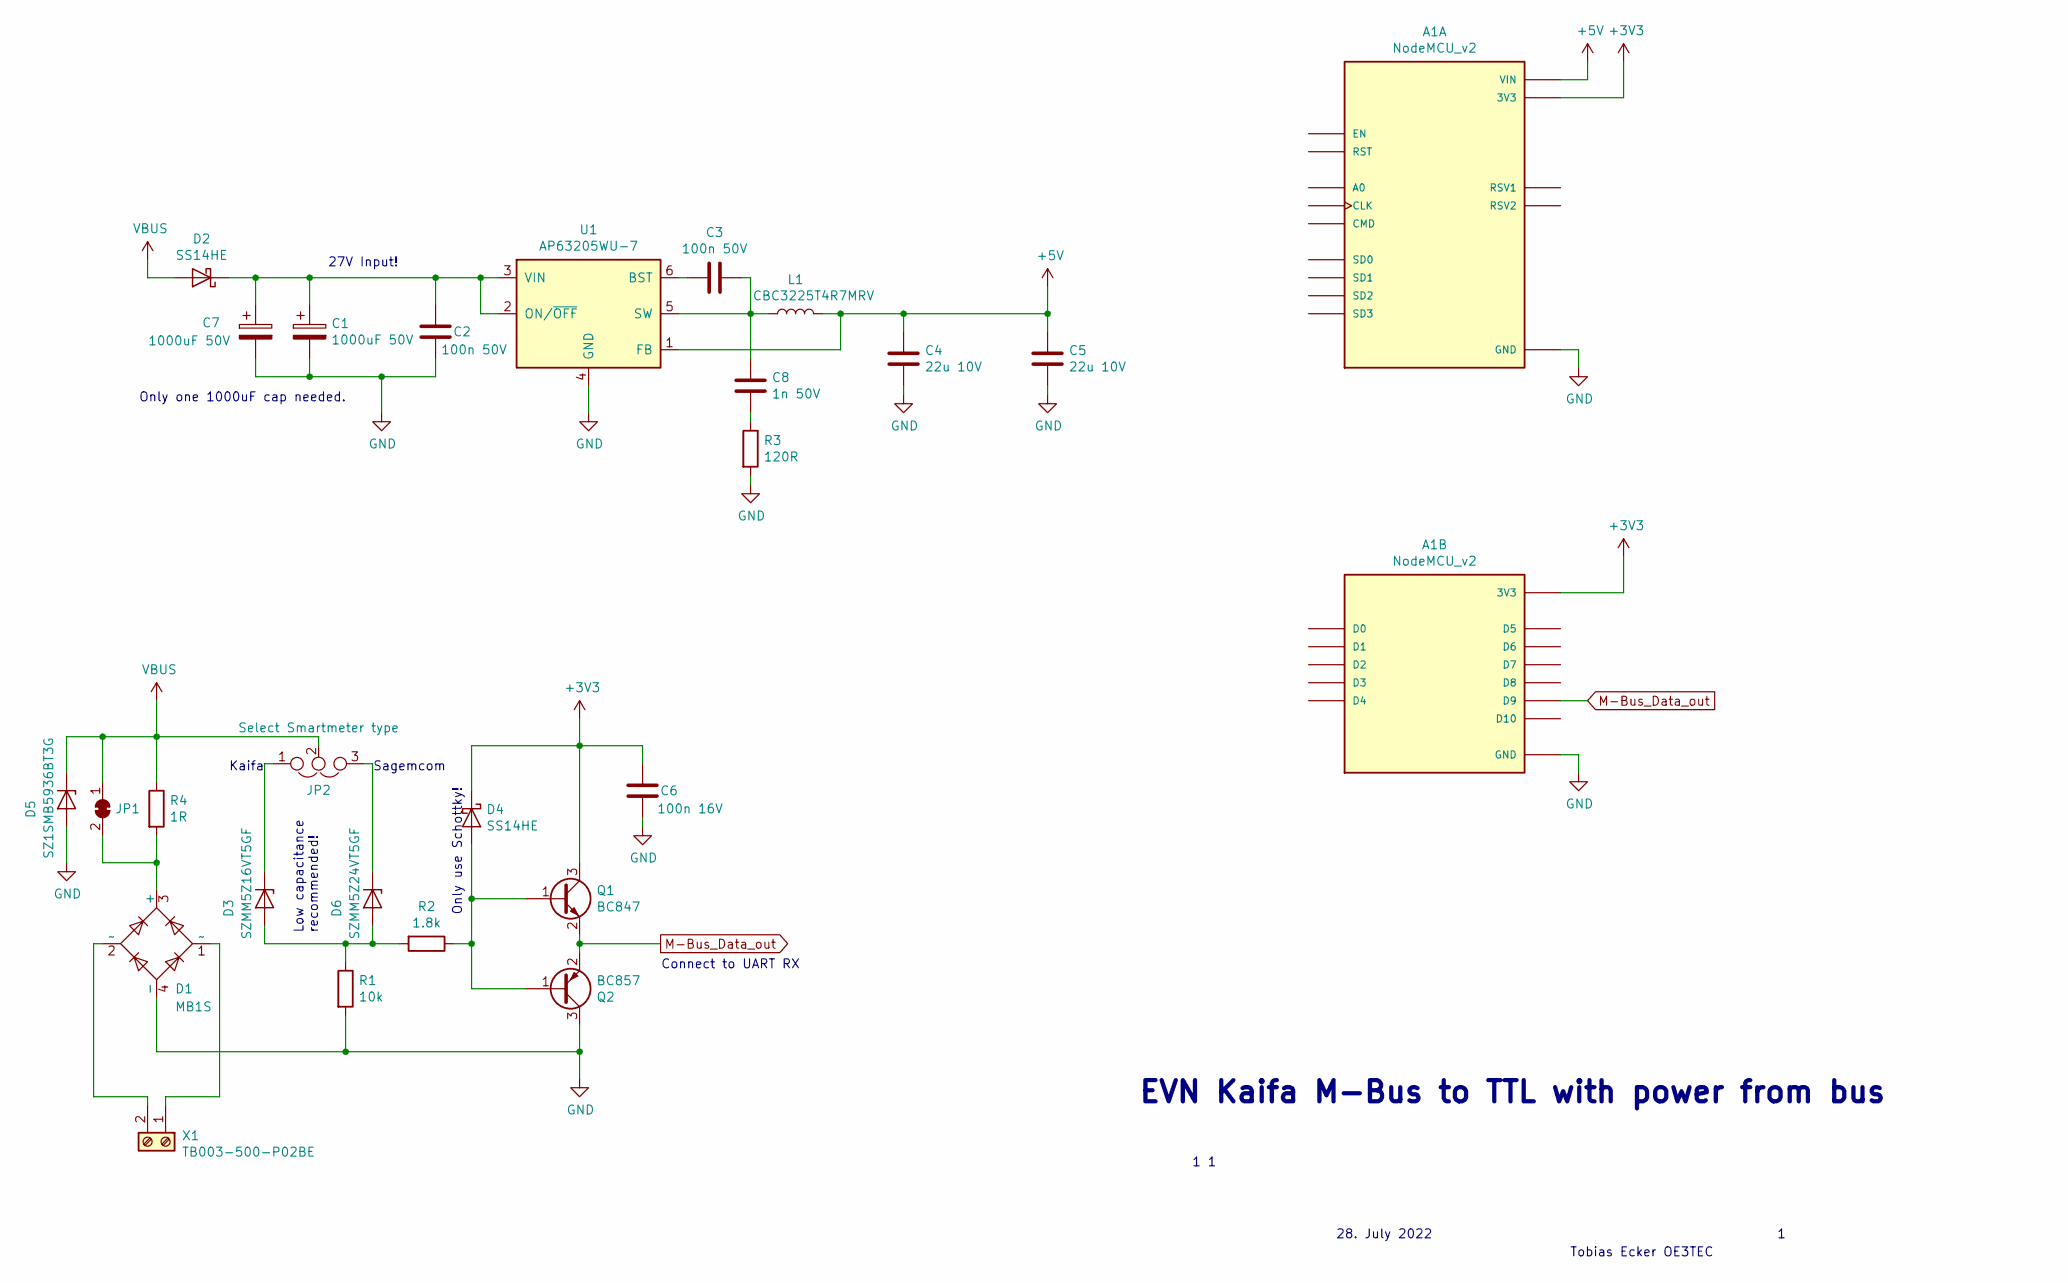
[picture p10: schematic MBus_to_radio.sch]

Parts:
A1: NodeMCU_v2; SEEED_113990105; PARTREV N/A
C1, C7: 1000uF 50V; CP_Radial_D10.0mm_P5.00mm
C2, C3: 100n 50V; C_0603_1608Metric
C4, C5: 22u 10V; C_1206_3216Metric
C6: 100n 16V; C_0603_1608Metric
C8: 1n 50V; C_0603_1608Metric
D1: MB1S; TO-269AA
D2, D4: SS14HE; D_SOD-323
D3: SZMM5Z16VT5GF; D_SOD-523
D5: SZ1SMB5936BT3G; D_SMB-SMC_Universal_Handsoldering
D6: SZMM5Z24VT5GF; D_SOD-523
JP1: SolderJumper_2_Bridged; SolderJumper-2_P1.3mm_Bridged_RoundedPad1.0x1.5mm
JP2: Select Smartmeter type; PinHeader_1x03_P2.54mm_Vertical
L1: CBC3225T4R7MRV; L_1210_3225Metric
Q1: BC847; SOT-23
Q2: BC857; SOT-23
R1: 10k; R_0603_1608Metric
R2: 1.8k; R_0603_1608Metric
R3: 120R; R_0603_1608Metric
R4: 1R; R_1812_4532Metric
U1: AP63205WU-7; TSOT-23-6
X1: TB003-500-P02BE; CUI_TB003-500-P02BE

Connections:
+3V3: A1.J1_11 (3V3), A1.J2_6 (3V3), A1.J2_15 (3V3), C6.2, D4.1 (K), Q1.3 (C)
+5V: A1.J1_15 (VIN), C4.2, C5.2, L1.2, U1.1 (FB)
GND: A1.J1_10 (GND), A1.J1_14 (GND), A1.J2_7 (GND), A1.J2_14 (GND), C1.2, C2.1, C4.1, C5.1, C6.1, C7.2, D1.4 (-), D5.2 (A), Q2.3 (C), R1.2, R3.2, U1.4 (GND)
M-Bus_Data_out: A1.J2_12 (D9), Q1.2 (E), Q2.2 (E)
unnamed: C1.1, C2.2, C7.1, D2.1 (K), U1.2 (ON/~OFF), U1.3 (VIN)
unnamed: C3.1, U1.6 (BST)
unnamed: C3.2, C8.2, L1.1, U1.5 (SW)
unnamed: C8.1, R3.1
unnamed: D1.1 (~~), X1.1
unnamed: D1.2 (~~), X1.2
unnamed: D1.3 (+), JP1.2 (B), R4.2
unnamed: D3.1 (K), JP2.1
unnamed: D3.2 (A), D6.2 (A), R1.1, R2.2
unnamed: D4.2 (A), Q1.1 (B), Q2.1 (B), R2.1
unnamed: D6.1 (K), JP2.3
VBUS: D2.2 (A), D5.1 (K), JP1.1 (A), JP2.2, R4.1

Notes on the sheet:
EVN Kaifa M-Bus to TTL with power from bus
1 1
28. July 2022
Tobias Ecker OE3TEC
Only use Schottky!
Low capacitance recommended!
Connect to UART RX
27V Input!
Only one 1000uF cap needed.
Kaifa
Sagemcom

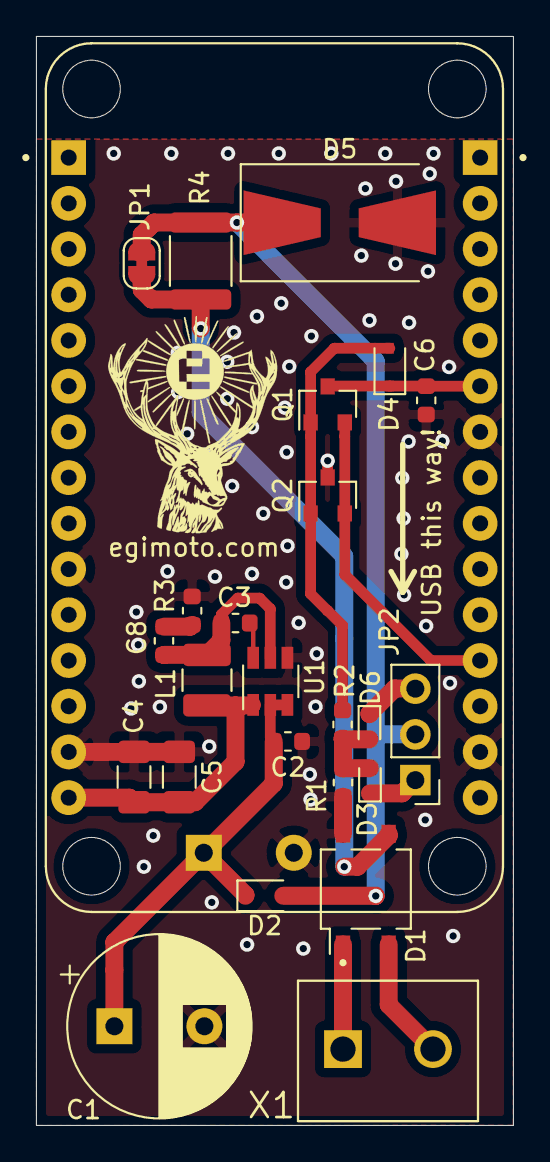
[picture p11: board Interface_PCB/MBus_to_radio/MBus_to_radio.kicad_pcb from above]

Board: 2 copper layers, 26.5 x 60.5 mm, 26 parts (1 on the bottom side), 16 nets.

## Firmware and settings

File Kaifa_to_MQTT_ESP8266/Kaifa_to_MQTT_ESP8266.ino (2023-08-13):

/**
* ESP8266 based power meter M-Bus to mqtt gateway v2.1
* - Tobias Ecker OE3TEC 2022
* - Matthias Preymann PreyMa 2023
*
* Project url: https://github.com/Tobias0110/EVN_Kaifa_ESP_MQTT
* Licensed as GPL v2.0
**/

/**
* Building the project using the Arduino IDE
* - Build the static webpage first by running the script. (Install dependencies with npm first.)
* - Install the ESP-Module as a compilation target
*   - Add board config repository: File --> Preferences --> Paste URL into "Additional boards manager URLs": http://arduino.esp8266.com/stable/package_esp8266com_index.json
*   - Install the toolchain: Tools --> Boards Manager --> Install: esp8266
*   - Select the specific ESP module: Tools --> Board --> ESP2866 Boards --> NodeMCU 1.0 (ESP-12E Modul)
* - Open the Library Manager and intstall the dependencies listed below (Crypto, PubSubClient, CRC)
* - Download additional dependcies from their respective Github respositorities and put them into your Arduino/Libraries directory (ESP8266TrueRandom)
* - Click verify to check if the project buildes without errors
* - Connect the ESP module and click upload like for any other Arduino-like micro controller
*
* Resources:
* M-Bus Specification (version "late 90s"):
* - https://m-bus.com/assets/downloads/MBDOC48.PDF
*
* Smart meter customer data port description (Multiple Austrian energy companies):
* - https://www.netz-noe.at/Download-(1)/Smart-Meter/218_9_SmartMeter_Kundenschnittstelle_lektoriert_14.aspx
* - https://stadtwerkeschwaz.at/pdfs/Technische%20Beschreibung%20Kundenschnittstelle%20SWS%20Smart%20Meter.pdf
* - https://www.salzburgnetz.at/content/dam/salzburgnetz/dokumente/stromnetz/Technische-Beschreibung-Kundenschnittstelle.pdf
* - https://www.tinetz.at/infobereich/smart-meter/anleitungen-fragen-antworten/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
*
* Python implementation of a DLMS to XML converter:
* - https://github.com/Gurux/Gurux.DLMS.Python/
**/

#ifdef _MSC_VER
#define _CRT_SECURE_NO_WARNINGS
#endif

#ifndef ARDUINO
#include <iostream>
#include <string>
#include <map>
#include <iomanip>
#include <cassert>
#include <random>
#include <conio.h>
#include <stdio.h>
#include <windows.h>

#include "Crypto-0.4.0/src/Crypto.h"
#include "Crypto-0.4.0/src/AES.h"
#include "Crypto-0.4.0/src/GCM.h"
#include "CRC-master/src/CRC32.h"
#include "Chacha20Poly1305.h"

#else

/**
* Dependencies:
* - ESP8266 Arduino support (Arduino team - GNU LGPL v2.1): https://github.com/esp8266/Arduino
* - Crypto: (Rhys Weatherley - MIT) https://rweather.github.io/arduinolibs/crypto.html
* - PubSubClient: (Nicholas O'Leary - MIT) https://pubsubclient.knolleary.net/
* - CRC: (Rob Tillaart - MIT) https://github.com/RobTillaart/CRC
*
* Dependencies (Manual installation required):
* - ESP8266TrueRandom: (Marvin Roger - GNU LGPL v3.0) https://github.com/marvinroger/ESP8266TrueRandom
**/

#include <ESP8266WiFi.h>
#include <WiFiClientSecure.h>
#include <ESP8266WebServer.h>
#include <PubSubClient.h>
#include <EEPROM.h>
#include <Arduino.h>
#include <Crypto.h>
#include <AES.h>
#include <GCM.h>
#include <CRC32.h>
#include <ESP8266TrueRandom.h>

#endif


// Based on https://stackoverflow.com/questions/35087781/using-line-in-a-macro-definition
// ... and based on SerenityOS' ErrorOr/Try pattern (see below). This could be way nicer
// if MSVC supported GCC expression statements ({ ... })
#define TOKEN_PASTE(x, y) x##y
#define CAT(x,y) TOKEN_PASTE(x,y)

#define TRYGET( varName, expression ) \
    auto CAT(maybeValue_, __LINE__) = expression; \
    if( CAT(maybeValue_, __LINE__).isError() ) { \
        return CAT(maybeValue_, __LINE__).error(); \
    } \
    auto varName= NoStl::move(CAT(maybeValue_, __LINE__).value())

#define TRY( expression ) \
    { \
        auto CAT(maybeValue_, __LINE__) = expression; \
        if( CAT(maybeValue_, __LINE__).isError() ) { \
            return CAT(maybeValue_, __LINE__).error(); \
        } \
    }

#define RETHROW( expression, message ) \
    { \
        auto CAT(maybeValue_, __LINE__) = expression; \
        if( CAT(maybeValue_, __LINE__).isError() ) { \
            return Error{ message }; \
        } \
    }


#ifdef _DEBUG
#define DEBUG_PRINTING 1
#else
#define DEBUG_PRINTING 0
#endif

using u8 = uint8_t;
using u16 = uint16_t;
using u32 = uint32_t;
using u64 = uint64_t;
using i8 = int8_t;
using i16 = int16_t;
using i32 = int32_t;
using i64 = int64_t;


namespace NoStl {

  template<typename>
  constexpr bool isLValueReference = false;

  template<typename T>
  constexpr bool isLValueReference<T&> = true;

  template<typename T>
  struct removeReference { using type = T; };

  template<typename T>
  struct removeReference<T&> { using type = T; };

  template<typename T>
  struct removeReference<T&&> { using type = T; };

  template<typename T>
  constexpr typename removeReference<T>::type&& move( T&& arg ) {
    return static_cast<typename removeReference<T>::type&&>(arg);
  }

  template<typename T>
  constexpr T&& forward( typename removeReference<T>::type& x ) noexcept { // forward an lvalue as either an lvalue or an rvalue
    return static_cast<T&&>(x);
  }

  template<typename T>
  constexpr T&& forward( typename removeReference<T>::type&& x ) noexcept { // forward an rvalue as an rvalue
    static_assert(!isLValueReference<T>, "bad forward call");
    return static_cast<T&&>(x);
  }


  template<typename> class Optional;
  template<typename> class UniquePtr;
}

template<typename>
class SerialStream;
class Error;
template<typename>
class ErrorType;
class Buffer;
template<int>
class LocalBuffer;
class OwnedBuffer;
template<typename>
class IndexReader;
template<typename>
class SerialUnbufferedReader;
class BufferReaderBase;
class BufferReader;
template<typename>
class SerialBufferReader;
class BufferPrinter;
class MqttSender;
class SettingsField;
template<typename>
class EEPROMSettings;
template<typename>
class EEPROMHandle;
class MBusLinkFrame;
class MBusTransportFrame;
class DlmsApplicationFrame;
class DlmsStructureNode;
class DlmsNodeAllocator;
class DlmsReader;
class CosemDataField;
class CosemScaledValue;
class CosemTimestamp;
class CosemMeterNumber;
class CosemData;
template<typename>
class MqttSenderImplBase;
template<typename>
class MqttRawSender;
template<typename>
class MqttTopicSender;
template<typename>
class MqttJsonSender;
class JsonFormData;
class ParsedJsonFormFieldsBase;
template<int>
class ParsedJsonFormFields;
class EncryptedFormData;
class FormDataEncryptor;
template<typename T>
class WebServerPrinter;

/**
* Reimplement a few useful standard classes in the absence of the STL
**/
namespace NoStl {
  template<typename T>
  class Optional {
  public:
    Optional() : data{ .placeholder = 0 }, valueFlag{ false } {}

    Optional( const Optional& ) = delete;
    Optional( Optional&& other ) : valueFlag{ other.valueFlag } {
      if( valueFlag ) {
        new(&data.value) T( move( other.data.value ) );
        other.clear();
      }
    }

    template<typename ... TArgs>
    Optional( TArgs&& ... args ) : data{ .value{ NoStl::forward<TArgs>( args )... } }, valueFlag{ true } {}

    ~Optional() {
      clear();
    }

    bool hasValue() const { return valueFlag; }
    operator bool() const { return valueFlag; }

    T& value() { assert( valueFlag ); return data.value; }
    const T& value() const { assert( valueFlag ); return data.value; }

    void clear() {
      if( valueFlag ) {
        data.value.~T();
        valueFlag = false;
      }
    }

    template<typename U>
    Optional& operator=( U&& val ) {
      if( valueFlag ) {
        data.value = forward<U>( val );
      } else {
        new(&data.value) T( forward<U>( val ) );
        valueFlag = true;
      }
      return *this;
    }

    template<typename U>
    Optional& operator=( Optional<U>&& other ) {
      clear();
      if( other.valueFlag ) {
        *this = std::move( other.data.value );
        other.clear();
      }
      return *this;
    }

  private:
    union Storage {
      char placeholder;
      T value;

      ~Storage();
    };

    Storage data;
    bool valueFlag{ false };
  };

  // Implement the union destructor out of line to prevent the Arduino IDE from creating
  // bogus prototypes all over the file
  template<typename T>
  Optional<T>::Storage::~Storage() {}

  template<typename T>
  class UniquePtr {
  public:
    UniquePtr() : ptr{ nullptr } {};
    UniquePtr( const UniquePtr& ) = delete;

    template<typename U>
    UniquePtr( UniquePtr<U>&& other ) : ptr{ other.release() } {}

    template<typename U>
    explicit UniquePtr( U* p ) : ptr{ p } {}

    explicit UniquePtr( T* p ) : ptr{ p } {}

    ~UniquePtr() {
      reset();
    }

    template<typename U>
    UniquePtr& operator=( UniquePtr<U>&& other ) {
      reset();
      ptr = other.ptr;
      other.ptr = nullptr;
      return *this;
    }

    T& operator*() { assert( ptr ); return *ptr; }
    const T& operator*() const { assert( ptr ); return *ptr; }

    T* operator->() { assert( ptr ); return ptr; }
    const T* operator->() const { assert( ptr ); return ptr; }

    operator bool() const { return ptr; }

    void reset() {
      if( ptr ) {
        delete ptr;
        ptr = nullptr;
      }
    }

    T* release() {
      auto* p = ptr;
      ptr = nullptr;
      return p;
    }

    T* get() {
      return ptr;
    }

  private:
    template<typename U>
    friend class UniquePtr;

    T* ptr{ nullptr };
  };

  template<typename T, typename ...Args>
  UniquePtr<T> makeUnique( Args&&... args ) {
    return UniquePtr<T>{ new T( forward<Args>( args )... ) };
  }
}


template<typename T>
class SerialStream {
public:
  SerialStream( T& s ) : serial{ s } {}

  template<typename U>
  SerialStream& operator << ( const U& x ) {
    serial.print( x );
    return *this;
  }

private:
  T& serial;
};

/**
* Mock a bunch of different classes, functions and globals from the Arduino Libraries,
* to make the same code compile on a Desktop machine. There compilation is way faster
* and a real debugger is available, wich improves developer (my) happiness.
**/
#ifndef ARDUINO
#define SERIAL_8N1 0x00
#define SERIAL_8E1 0x01
#define D0     0x00
#define OUTPUT 0x00
#define LOW    0x00
#define HIGH   0x01
#define WL_CONNECTED 0x0A
#define PROGMEM
#define PGM_P const char*
#define FPSTR(pstr_pointer) (reinterpret_cast<const __FlashStringHelper *>(pstr_pointer))
#define F(string_literal) (FPSTR(PSTR(string_literal)))
struct __FlashStringHelper {};

class String {
public:
  String() = default;
  String( const char* s ) : data{ s } {}
  String( const String& ) = default;
  String( String&& s ) : data{ std::move( s.data ) } {}
  String( std::string s ) : data{ std::move( s ) } {}

  bool isEmpty() const { return data.size() == 0; }

  bool equalsIgnoreCase( const String& s ) const {
    return std::equal( data.begin(), data.end(), s.data.begin(), s.data.end(), []( char a, char b ) {
      return tolower( a ) == tolower( b );
    } );
  }

  bool equals( const String& s ) const { return data == s.data; }

  i32 indexOf( const char* s, u32 start = 0 ) const {
    auto x = data.find( s, start );
    return x == std::string::npos ? -1 : x;
  }
  i32 indexOf( char s, u32 start = 0 ) const {
    auto x = data.find( s, start );
    return x == std::string::npos ? -1 : x;
  }

  std::string& str() { return data; }
  const std::string& str() const { return data; }
  const char* c_str() const { return data.c_str(); }

  u32 length() const { return data.length(); }

  char& operator[]( u32 idx ) { return data[idx]; }
  const char& operator[]( u32 idx ) const { return data[idx]; }

  char* begin() { return (char*)data.data(); }

private:
  std::string data;
};

std::ostream& operator<<( std::ostream& o, const String& s ) {
  return o << s.str();
}

class DummyESP8266TrueRandom {
public:
  void memfill( char* data, u32 size ) {
    for( u32 i = 0; i != size; i++ ) {
      data[i] = dist( randomDevice );
    }
  }
private:
  // Always seed with the same value, for easier testing
  std::default_random_engine randomDevice{ 0x0 };
  std::uniform_int_distribution<u16> dist{ 0, 255 };
};

DummyESP8266TrueRandom ESP8266TrueRandom;

namespace experimental {
  namespace crypto {
    struct ChaCha20Poly1305 {
      static void encrypt(
        void* data, const size_t dataLength, const void* key, const void* keySalt, const size_t keySaltLength,
        void* resultingNonce, void* resultingTag, const void* aad = nullptr, const size_t aadLength = 0 ) {
        ::ChaCha20Poly1305::encrypt( data, dataLength, key, keySalt, keySaltLength, resultingNonce, resultingTag, aad, aadLength );
      }
      static bool decrypt(
        void* data, const size_t dataLength, const void* key, const void* keySalt, const size_t keySaltLength,
        const void* encryptionNonce, const void* encryptionTag, const void* aad = nullptr, const size_t aadLength = 0 ) {
        return ::ChaCha20Poly1305::decrypt( data, dataLength, key, keySalt, keySaltLength, encryptionNonce, encryptionTag, aad, aadLength );
      }
    };
  }
}

void delay( uint32_t );
u32 millis() {
  static u32 time = 100;
  return time += 50;
}
#endif
#if DEBUG_PRINTING


/**
* Define globals for debug printing and assertions. When mocking the system on a desktop
* computer debug printing and assertions are always active. Depending on 'DEBUG_PRINTING'
* constant assertions and the debug printing stream are either turned on or completely
* removed.
**/
#ifdef ARDUINO

SerialStream<decltype(Serial)> debugSerialStream{ Serial };

#define debugOut debugSerialStream
#define debugEndl "\r\n"

void handleAssertionFailure( u32 lineNumber ) {
  debugOut << "\r\n\r\nAssertion failed on line number " << lineNumber << debugEndl;
  Serial.flush();

  // Halt the system
  while( true ) {}
}

#undef assert
#define assert( cond ) \
    do {\
        if( !(cond) ) { \
            handleAssertionFailure( __LINE__ ); \
        } \
    } while(0)

#else

#define debugOut std::cout
#define debugEndl std::endl;

#endif

#else

struct DebugSink {
  template<typename T>
  const DebugSink& operator<<( const T& ) const { return *this; }
};

#define debugOut DebugSink()
#define debugEndl 0;

#undef assert
#define assert(...) do{}while(0)

#endif


// Heavily inspired by SerenityOS: https://github.com/SerenityOS/serenity/blob/master/AK/Error.h

class Error {
public:
  explicit Error( const char* m ) : msg( m ) {}

  const char* message() const { return msg; }

private:
  const char* msg;
};

struct EmptyType {};

template<typename T>
class ErrorOr {
public:
  ErrorOr( Error e ) : storage{ .error{ NoStl::move( e ) } }, storesError{ true } {}

  template<typename ...Args>
  ErrorOr( Args&& ... args ) : storage{ .value{ NoStl::forward<Args>( args )... } }, storesError{ false } {}

  ~ErrorOr() {
    if( storesError ) {
      storage.error.~Error();
    } else {
      storage.value.~T();
    }
  }

  bool isError() const { return storesError; }
  Error& error() { assert( isError() ); return storage.error; }
  T& value() { assert( !isError() ); return storage.value; }

private:
  union Storage {
    Error error;
    T value;

    ~Storage();
  } storage;

  bool storesError;
};

// Implement the union destructor out of line to prevent the Arduino IDE from creating
// bogus prototypes all over the file
template<typename T>
ErrorOr<T>::Storage::~Storage() {}

template<>
class ErrorOr<void> : public ErrorOr<EmptyType> {
public:
  using ErrorOr<EmptyType>::ErrorOr;
};
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
void loop() {
  // Try to read a mbus packet and transmit it via mqtt
  if( Serial.available() ) {
    debugOut << "Waiting..." << debugEndl;
    auto error = waitForAndProcessPacket();
    if( error.isError() ) {
      debugOut << "\r\n\r\nCaught error in ::waitForAndProcessPacket: " << error.error().message() << debugEndl;

      // Resync
      u8 secondsWithoutSerialData = 0;
      while( (Serial.available() > 0) || (secondsWithoutSerialData < 2) ) {
        flushSerial();
        delay( 1000 );
        secondsWithoutSerialData = !Serial.available() ? secondsWithoutSerialData + 1 : 0;
      }
    }

    // Heart beat LED blink
    digitalWrite( D0, LOW );
    delay( 100 );

    debugOut << "Done" << debugEndl;
  }

  digitalWrite( D0, HIGH );
  webServer.handleClient();
}

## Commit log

2022-11-07 Update PCB infos
2022-11-07 added PCB data
    [MBus_to_radio-B_Cu.gbl, MBus_to_radio-B_Mask.gbs, MBus_to_radio-B_Paste.gbp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]
2022-11-29 Add some missing stl type traits capabilities
    [Kaifa_to_MQTT_ESP8266.ino]
2022-11-29 Add SerenityOS style error handling
    SerenityOS uses an ErrorOr<T> return value in fallible functions instead of exceptions. We don't have exceptions either so let's do the same (without manually turning them on and unnecessary increasing binary size).
    [Kaifa_to_MQTT_ESP8266.ino]
2022-11-29 Add m-bus frame parsing
    Each m-bus link frame contains a m-bus transport frame.
2022-11-29 Add dlms frame decryption
    Parsing this frame makes a few assumptions, like the type of link frame and the decryption mode
2022-11-29 Implement dlms payload parsing
    Parsing dlms structures is pretty complicated and this implementation is based on the reverse engineering Tobias and I did. In other words its not complete but seems to be good enough for the data se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
2022-11-29 Implement cosem data parsing
    Extract cosem data like line voltage, current and phase shift from the dlms structure.
2022-11-30 Add EEPROM storage slots to store settings
2022-11-30 Add mock classes for Arduino libs
    This allows the code to be run on a desktop computer for easier developement and debugging.
2022-12-02 Print eeprom settings on startup
2022-12-11 Implement optional debug printing for esp builds
2022-12-11 Debug print the wifi IP
2022-12-11 Debug print during mqtt setup
2022-12-11 Use readBytes to prevent watch dog timer trigger
    Looping for an extended amount of time trips the watch dog timer. `readBytes` handles the reseting automatically.
    [Kaifa_to_MQTT_ESP8266.ino]
2022-12-11 Fix shadowed `showSetup` flag and remove case sensitivity
    [Kaifa_to_MQTT_ESP8266.ino]
2022-12-11 Switch to mbus serial config at the end of setup
2022-12-11 Rename vars in waitForAndProcessPacket to be confided
    After `TRYGET` the variables are guaranteed to contain values instead of errors.
    [Kaifa_to_MQTT_ESP8266.ino]
2022-12-11 Make connecting to the mqtt broker fallible
    [Kaifa_to_MQTT_ESP8266.ino]
2022-12-11 Debug print when connecting to mqtt broker
    [Kaifa_to_MQTT_ESP8266.ino]
2022-12-22 Fix use after free of the mqtt server address
    The PubSubClient library allows to set the domain of the mqtt server to connect to as a string. However, it only stores a pointer and does not copy the contents into an owned buffer. Therefore, the string has to live along side the PubSubClient object.
    [Kaifa_to_MQTT_ESP8266.ino]
2022-12-22 Use a lower serial timeout that might actually fire
    The implementation of the Serial lib for ESP8266 has a silent limit for timeouts. If a timeout larger than 26.8s is encountered, the internally polled timer will never expire.
2022-12-22 Give a better assertion error message
    [Kaifa_to_MQTT_ESP8266.ino]
2022-12-22 Make `ensureBytes()` in SerialBufferReader fallible
    Instead of just asserting whether all requested bytes were reads, timeouts are now handled as errors.
    [Kaifa_to_MQTT_ESP8266.ino]
2022-12-22 Add debug printing to MqttJsonSender
2022-12-22 Extend DummySerial interface
    Add two missing methods to make the code work on Desktop again.
    [Kaifa_to_MQTT_ESP8266.ino]
2022-12-22 Add EEPROM clearing
    - The eeprom can be cleared before entering the setup.
    - The setup wizard provides currently stored values as default values.
    - Move field security check into a method.
2022-12-26 Expect carriage return at the end of lines
2022-12-26 Validate certificate fingerprint
2022-12-27 update PCB V2 to version that was produced
    [MBus_to_radio-B_Cu.gbl, MBus_to_radio-B_Mask.gbs, MBus_to_radio-B_Paste.gbp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]
2022-12-28 Validate all text fields to only contain printable chars
2022-12-28 Make clear which kind of ssl certificate fingerprint is required
2022-12-28 Make certificate fingerprint a secure field
2022-12-28 Disable forced debug printing
2022-12-29 DummySerial: Return if console bytes are available
    This does not work perfectly, but with this `flushSerial()` can actually clear out the console buffer. However, it sometimes hangs the program as `WaitForSingleObject()` returns true, but `getch_()` still blocks.
    [Kaifa_to_MQTT_ESP8266.ino]
2022-12-29 Print correct error message on bad key pem header
    [Kaifa_to_MQTT_ESP8266.ino]
2022-12-30 Correctly store binary der data in eeprom
    The `set` method expects C strings and stops at the null terminator. Plus the offset calculation was bogus as it also offsets the buffer reading index.
    [Kaifa_to_MQTT_ESP8266.ino]
2022-12-30 Reset both der buffers after decoding base64
    [Kaifa_to_MQTT_ESP8266.ino]
2022-12-30 Assert that der file length is not larger than the settings field
2022-12-30 Add some simple mqtt domain name validation
    This validation is not exhaustive as it does not check each subdomain component. But it at least should help to prevent most typos when entering.
    [Kaifa_to_MQTT_ESP8266.ino]
2023-01-02 clear up HW dir
    [MBus_to_radio.sch]
2023-01-09 Correctly print DummyIPAddress
2023-01-09 Settings: Allow for pointers into the EEPROM buffer
    Do not copy every string out of the EEPROM object into a separate buffer. Instead just create a buffer object with a pointer into the EEPROM handle buffer, if it is a read-only operation. To prevent messing up the EEPROM data and the checksum, the returned buffer object should be taken as `const auto`.
    This change will come in handy for reading DER cert and key files stored in the EEPROM, which only need to be read by BearSSL during start up. In the future all of the EEPROM buffer memory should be freed by calling `end()` after startup.
    [Kaifa_to_MQTT_ESP8266.ino]
2023-01-10 Fix borked WebServerSecure
    There seems to be a bug in the Arduino libraries for the ESP8266: Whenever a WifiClientSecure and WifiServerSecure both exist running TLS, their inner state of the server gets messed up, after the client sent something. In this case, the pubsubclient disabled the webserver when sending a mqtt message. As a remedy the wifiClient and wifiServer are now destructed after each mqtt message and the whole stack is reinitialized. This seems to work, but is complicated, involves unnecessary work and might also be unstable. Further, receiving a mbus packet and triggering a mqtt message transmission might kill the webserver while it is handling a request...
    [Kaifa_to_MQTT_ESP8266.ino]
2023-01-10 Switch on the LED during setup
2023-01-10 Do the wifiClient/Server unblocking during the LED flicker time
    Instead of wasting100ms, do the wifi unblocking during this time, and just wait the remaining time at the end.
2023-01-11 Correctly check der buffer file length after decoding
    [Kaifa_to_MQTT_ESP8266.ino]
2023-01-11 Allow switching to custom webserver cert and key
2023-01-16 BufferReaders: Differentiate fallible methods by name
    Make it clear in the interface which methods can fail (return ErrorOr<>). This makes reader types interchangeable in templated parser functions, as the basic BufferReader implements both interface types.
    [Kaifa_to_MQTT_ESP8266.ino]
2023-01-16 LocalBuffer: Fix copy constructor
    The auto generated copy constructed also copies the internal base pointer, creating dangling pointers.
    [Kaifa_to_MQTT_ESP8266.ino]
2023-01-16 BufferPrinter: Allow sub classes to handle full state
    By overriding the `onBufferFull()` method, a subclass may handle the full state during printing. The method has to clear the internal buffer and return true on success.
2023-01-16 Add ESP8266TrueRandom as a dependency
    Unfortunately this library cannot be installed through the library manager. Instead the source files need to be manually dropped into the Arduino/Libraries directory.
2023-01-18 WebPageRenderer: Provide the whole template part to the render function
    Do not unwrap the argument in the renderer before sending it to the render function. This allows for more complex data to be stored in the template part argument. Currently the argument was upgraded 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
2023-01-18 Settings: Prevent EEPROM from marking itself dirty during reads
    Use `.getConstDataPtr()` in methods that only do reads, to prevent the EEPROM object from marking itself as dirty and committing to the cells on closing.
    [Kaifa_to_MQTT_ESP8266.ino]
2023-01-18 SettingsField: Add space calculation for only or without der files
2023-01-20 EEPROMHandle: Allow for moving to transfer handle
    This allows to prevent multiple handles being created, needlessly initializing the eeprom multiple times. Instead a single instance can be passed around and destroyed at the very end.
    [Kaifa_to_MQTT_ESP8266.ino]
2023-01-28 WebPage: Add optional message to the settings page
    This will be useful for error and success messages when changing a setting eg. validation errors for bad data in a form field
    [Kaifa_to_MQTT_ESP8266.ino]
2023-01-28 WebPage: Add wifi password repeat field and prevent vertical stretching
    [Kaifa_to_MQTT_ESP8266.ino]
2023-01-28 Doc: Fix typo in comment
    [Kaifa_to_MQTT_ESP8266.ino]
2023-01-28 webRequestIsAuthenticated: Fix typo in function name
    [Kaifa_to_MQTT_ESP8266.ino]
2023-01-29 WebPage: Link wifi repeated pwd field to correct label
    [Kaifa_to_MQTT_ESP8266.ino]
2023-01-30 DummyWebServerSecure: Return const refs to args to closer match real implementation
    The internal data structure needs to store `String` objects instead of `std::string`, as creating them on the fly locally results in returning a stale reference. `String` is currently not compatible with `std::map` therefore it was replaced by a vector for now.
    [Kaifa_to_MQTT_ESP8266.ino]
2023-01-30 WebPage: Generalize settings handler
    The authentication check, validation, settings storage, and the rendering of the settings page can be moved into a reusable function. This prevents code duplication for the different settings forms.
    [Kaifa_to_MQTT_ESP8266.ino]
2023-02-01 WebPage: Add reset button to each form
2023-02-01 WebPage: Fix typo in form submit buttons
    [Kaifa_to_MQTT_ESP8266.ino]
2023-02-05 Wifi: Always print the local IP after connecting
2023-07-09 FuncRef: Make MSVC compile the storage buffer
    Is this a compiler bug? Writing everything inline does not compile, with the compiler complaining the "As" parameter pack was not expanded, which it very much is. GCC does not trip over this.
    [Kaifa_to_MQTT_ESP8266.ino]
2023-08-07 WebPage: Implement symmetric encryption
    As HTTPS is dysfunctional, a custom encryption scheme is introduced based on the Chacha20 Poly1305 cipher which is provided by the Arduino libraries thanks to BearSSL.
    During the setup wizard a 16 byte key is set or automatically generated, that is later used to derive one time keys using HKDF with a one time salt. The web browser now has to execute a considerable amount of JS code for en-/decryption, as JS crypto functionality is not available in an insecure HTTP environment. Encryption nonce values double as form nonce values to prevent playback attacks.
    [Kaifa_to_MQTT_ESP8266.ino]
2023-08-07 Settings: Fix insecure mqtt mode
    [Kaifa_to_MQTT_ESP8266.ino]
2023-08-13 V3 HW added
    [MBus_to_radio-B_Cu.gbl, MBus_to_radio-B_Mask.gbs, MBus_to_radio-B_Paste.gbp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]
